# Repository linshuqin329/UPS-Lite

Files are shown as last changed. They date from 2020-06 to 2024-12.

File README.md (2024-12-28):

# UPS-Lite
UPS-Lite是一款专门为树莓派Zero所设计的UPS电源，采用一块1000mAh的聚合物锂电池进行供电，支持外部电源插入检测，支持边充边放，支持电池电量检测。

详细的使用说明请看项目文件中的使用说明文档。如有问题请联系我：416386001@qq.com

UPS-Lite is a UPS power supply specially designed for the Raspberry Pi Zero. It uses a 1000mAh polymer lithium battery for power supply, supports external power supply insertion detection, supports charging and discharging while supporting battery power detection. Support battery level detection.
 
For detailed instructions, please refer to the instructions in the project file. If you have any questions, please contact me: 416386001@qq.com

You can buy ups-lite from here   https://www.tindie.com/products/rachel/ups-lite-for-raspberry-pi-zero/

## Statement about fake UPS-Lite 
hello, first of all, thank you for your support of ups-lite. Recently, I have received feedback from many customers, they bought fake ups-lite, there are many problems, some can not read the accurate battery power value, some battery bulge phenomenon, and some serious damage to pi zero. If you buy a ups-lite like this picture, it says "Designed BY MJ" on the back, then it is a fake ups-lite, and it is recommended to stop using it for safety.

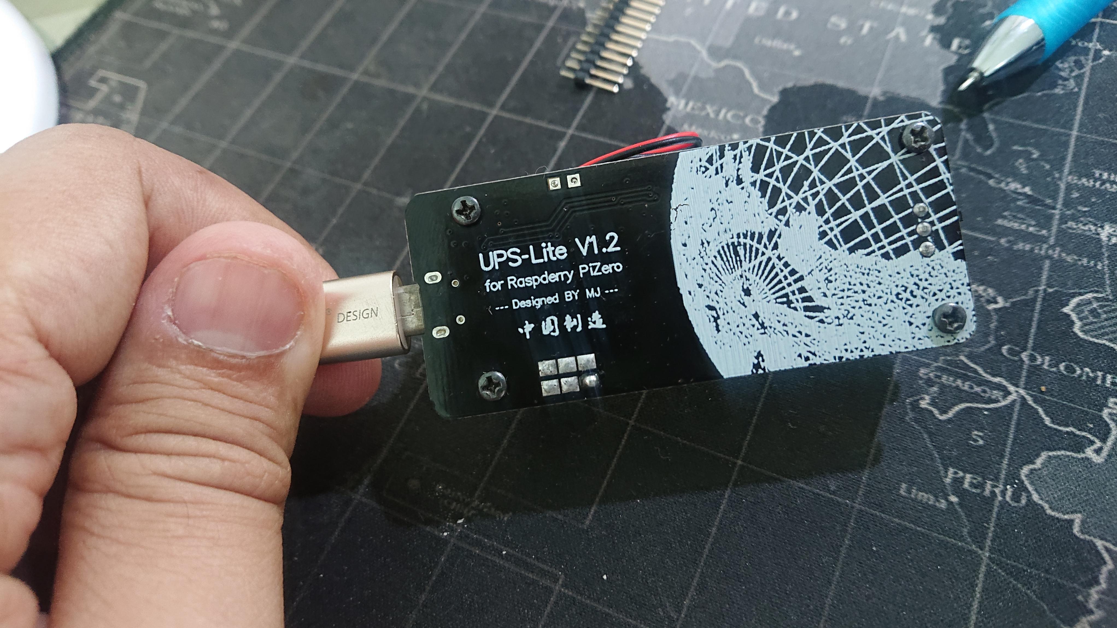
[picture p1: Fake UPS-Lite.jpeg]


# Case for UPS-Lite 
https://makerworld.com.cn/zh/models/767038#profileId-734749

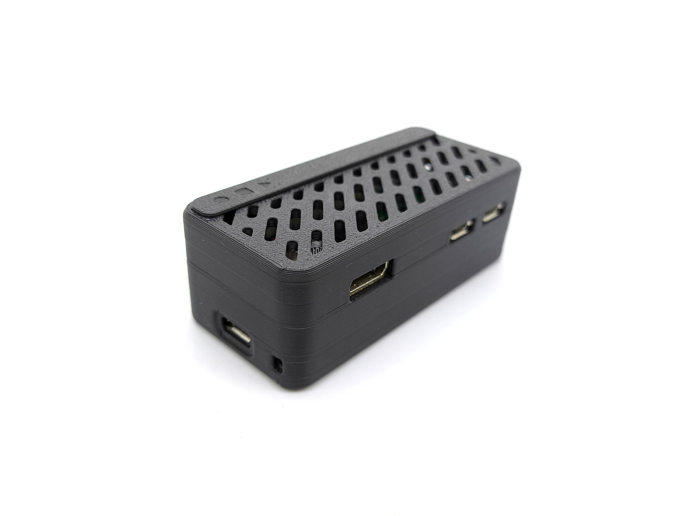
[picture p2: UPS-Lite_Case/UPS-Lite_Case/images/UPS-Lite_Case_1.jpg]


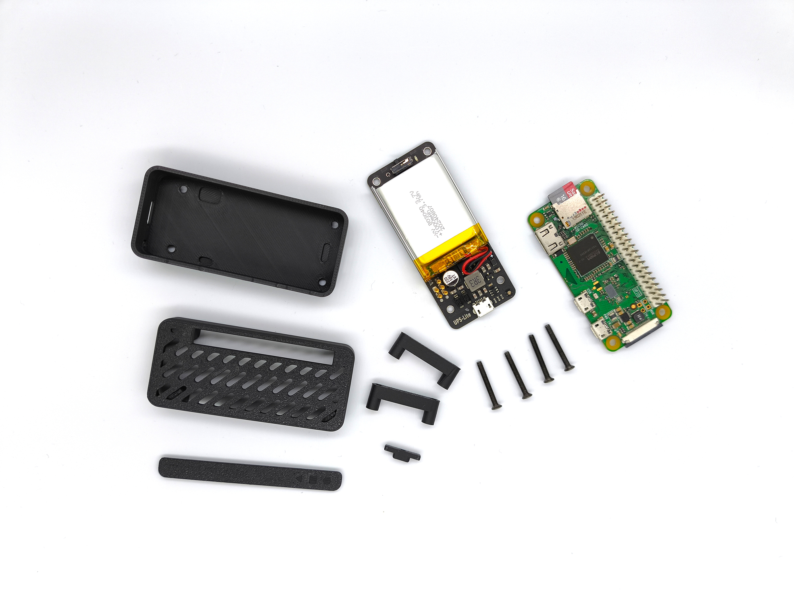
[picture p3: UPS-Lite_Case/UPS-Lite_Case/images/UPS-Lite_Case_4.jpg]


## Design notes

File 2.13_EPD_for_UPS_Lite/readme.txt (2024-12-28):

Instructions for using this board on the Pwnagotchi 

The pin definition on the e-ink screen circuit of this board is compatible with the waveshare  2.13 inch e-Paper HAT V4, 
which means that when you configure the Pwnagotchi screen, the screen type can be selected "waveshare_4"
ui.display.type = "waveshare_4"

For the use of the RTC chip DS1307Z, please refer to the detailed tutorial on Adafruit website
https://learn.adafruit.com/adding-a-real-time-clock-to-raspberry-pi

For the case, you can download the case 3D file, print and install it yourself
https://github.com/linshuqin329/UPS-Lite/tree/master/UPS-Lite_Case/UPS-Lite_EPD_Case
https://github.com/linshuqin329/UPS-Lite/tree/master/UPS-Lite_Case/UPS-Lite_EPD_Antenna_Case

//--------------------------------------------------------------------------------------------------------------------------------------

关于这个板子在Pwnagotchi 项目上的使用说明，

这个板子的墨水屏电路上的引脚定义与微雪的2.13寸墨水屏V4版本是兼容的，也就是说当你在配置Pwnagotchi 屏幕的时候，屏幕类型可以选择“waveshare_4”即可
ui.display.type = "waveshare_4"

关于RTC芯片DS1307Z的使用，请参考Adafruit网站上的相关详细教程
https://learn.adafruit.com/adding-a-real-time-clock-to-raspberry-pi

关于配套的外壳，可下载外壳3D文件，自行打印安装
https://github.com/linshuqin329/UPS-Lite/tree/master/UPS-Lite_Case/UPS-Lite_EPD_Case
https://github.com/linshuqin329/UPS-Lite/tree/master/UPS-Lite_Case/UPS-Lite_EPD_Antenna_Case

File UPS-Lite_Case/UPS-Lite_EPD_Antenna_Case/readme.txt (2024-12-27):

To install the shell, you need to prepare screws by yourself. Please refer to this file “ Screw Specification Requirement （M2.5+M2）”

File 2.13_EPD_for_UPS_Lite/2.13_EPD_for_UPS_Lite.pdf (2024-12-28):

# 2.13 inch E-Paper Display for UPS-Lite

UPS-Lite 专用 2.13 寸电子墨水屏显示板 | -- by XiaoJ

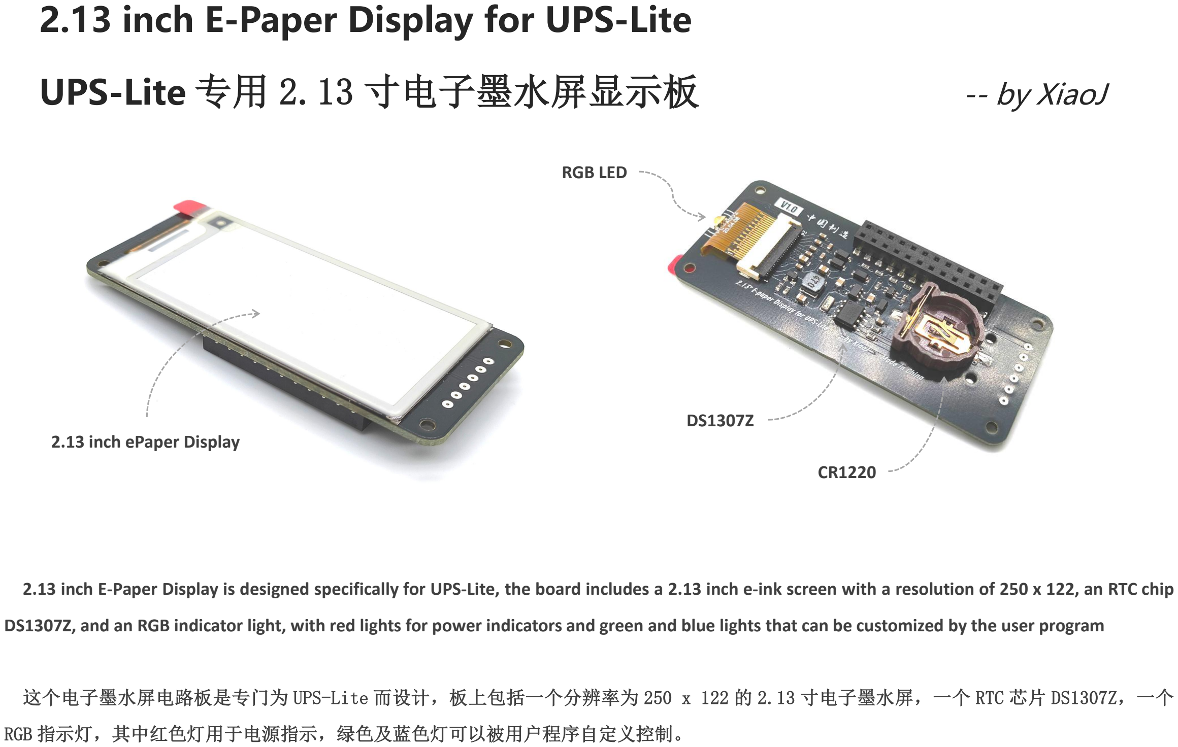
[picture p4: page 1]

### 2.13 inch ePaper Display

RGB LED

DS1307Z

CR1220

2.13 inch E-Paper Display is designed specifically for UPS-Lite, the board includes a 2.13 inch e-ink screen with a resolution of 250 x 122, an RTC chip DS1307Z, and an RGB indicator light, with red lights for power indicators and green and blue lights that can be customized by the user program

这个电子墨水屏电路板是专门为 UPS-Lite 而设计，板上包括一个分辨率为 250 x 122 的 2.13 寸电子墨水屏，一个 RTC 芯片 DS1307Z，一个

RGB 指示灯，其中红色灯用于电源指示，绿色及蓝色灯可以被用户程序自定义控制。

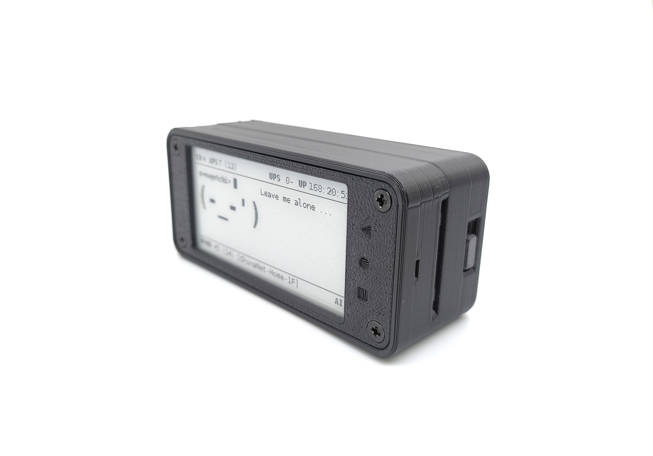
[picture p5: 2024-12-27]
UPS-Lite_Case/UPS-Lite_EPD_Case/images/UPS-Lite_EPD_Case_1.jpg

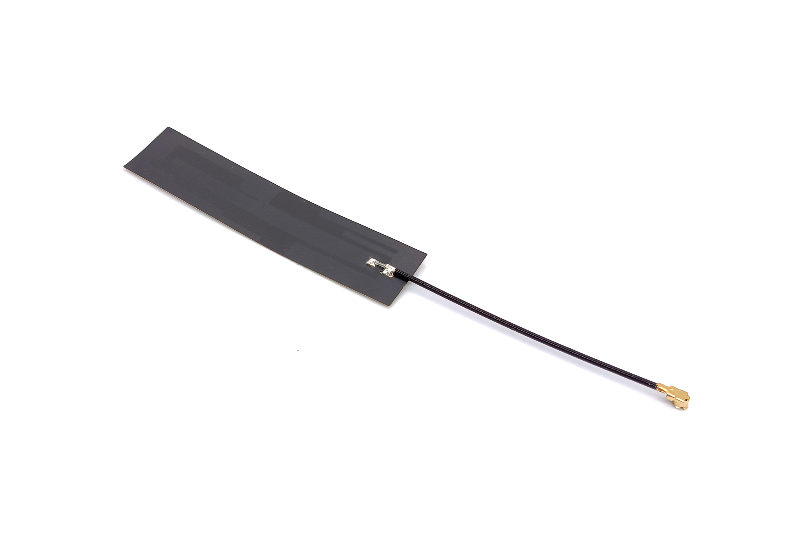
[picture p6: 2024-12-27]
UPS-Lite_Case/UPS-Lite_EPD_Antenna_Case/images/UPS-Lite_EPD_Antenna_Case_5.jpg

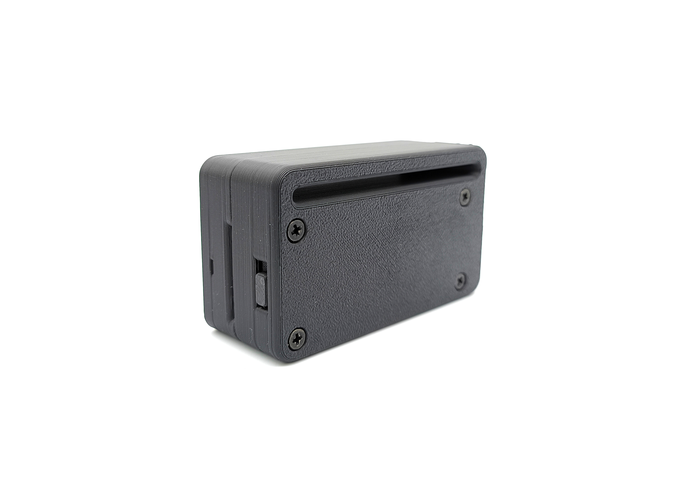
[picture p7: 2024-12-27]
UPS-Lite_Case/UPS-Lite_EPD_Antenna_Case/images/UPS-Lite_EPD_Antenna_Case_2.jpg

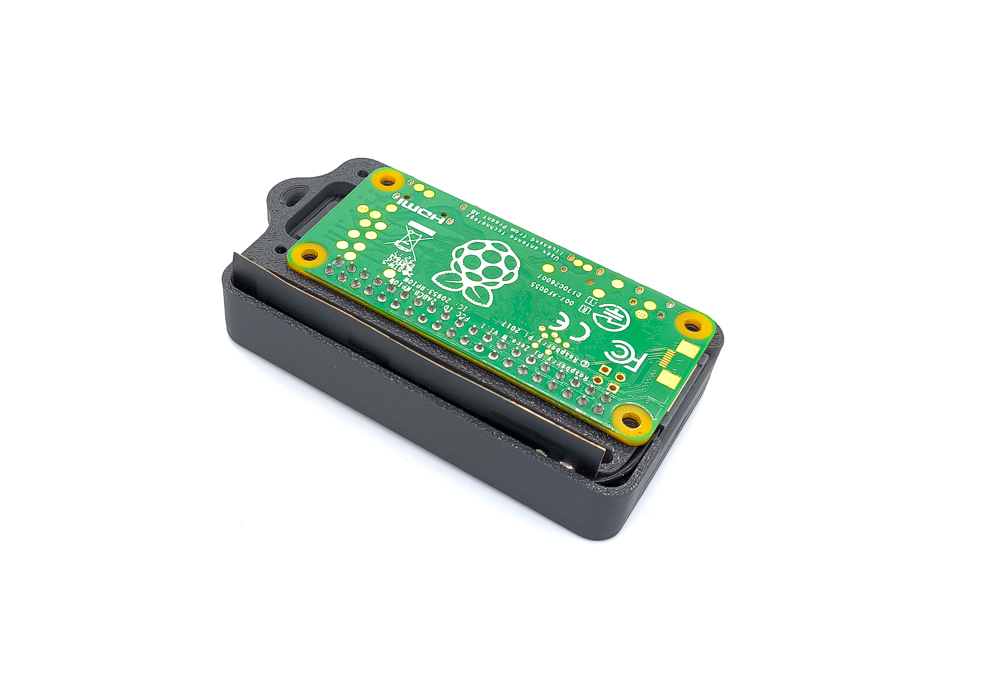
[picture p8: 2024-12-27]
UPS-Lite_Case/UPS-Lite_EPD_Antenna_Case/images/UPS-Lite_EPD_Antenna_Case_3.jpg

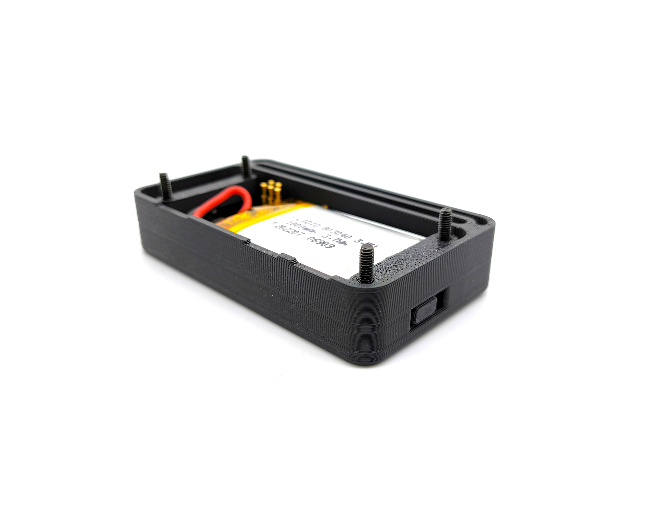
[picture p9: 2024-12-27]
UPS-Lite_Case/UPS-Lite_EPD_Antenna_Case/images/UPS-Lite_EPD_Antenna_Case_4.jpg

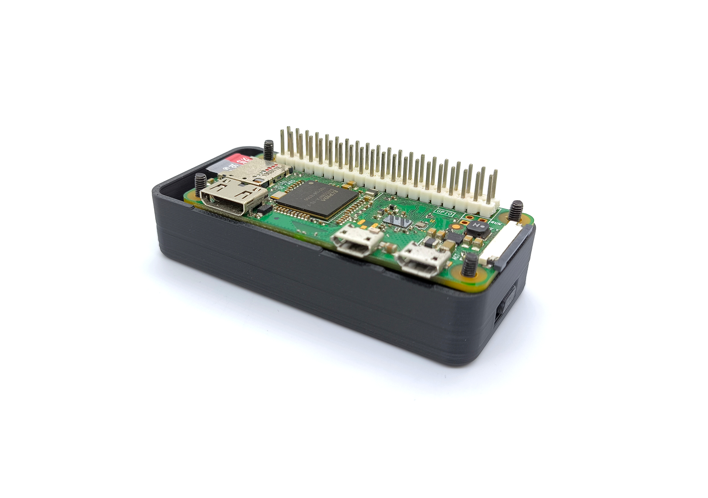
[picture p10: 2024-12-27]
UPS-Lite_Case/UPS-Lite_Case/images/UPS-Lite_Case_2.jpg

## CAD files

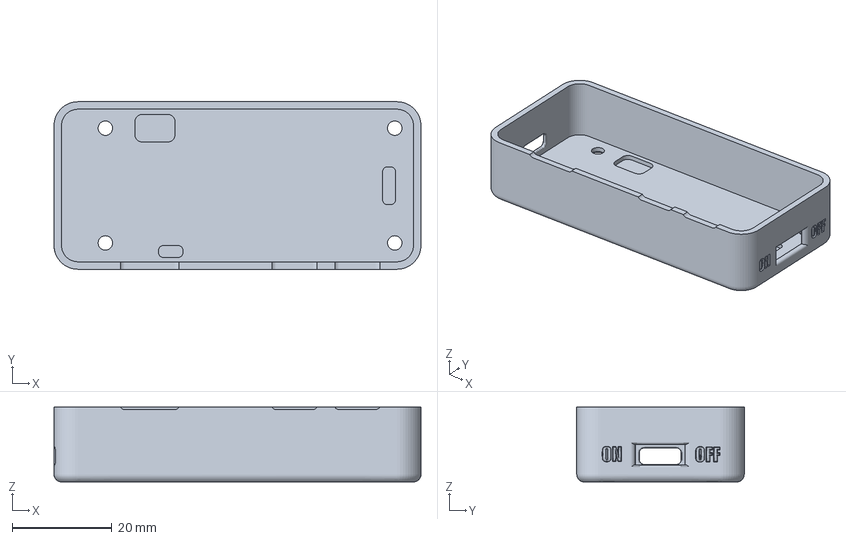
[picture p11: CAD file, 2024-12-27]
UPS-Lite_Case/UPS-Lite_Case/3mf/bottom cover.3mf
73.6 x 33.6 x 15.0 mm

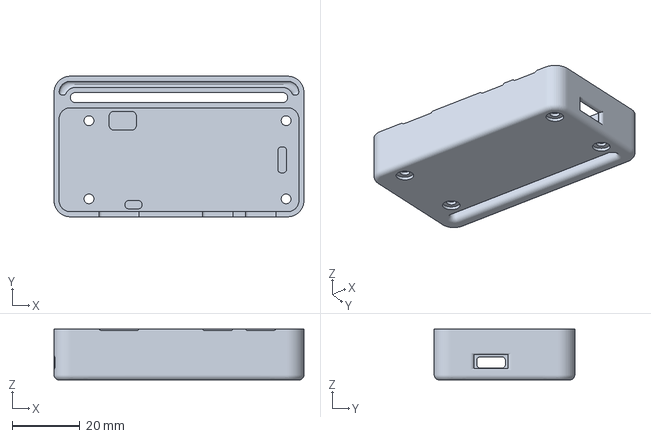
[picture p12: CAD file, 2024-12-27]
UPS-Lite_Case/UPS-Lite_EPD_Antenna_Case/3mf/bottom cover.3mf
73.6 x 41.4 x 15.0 mm

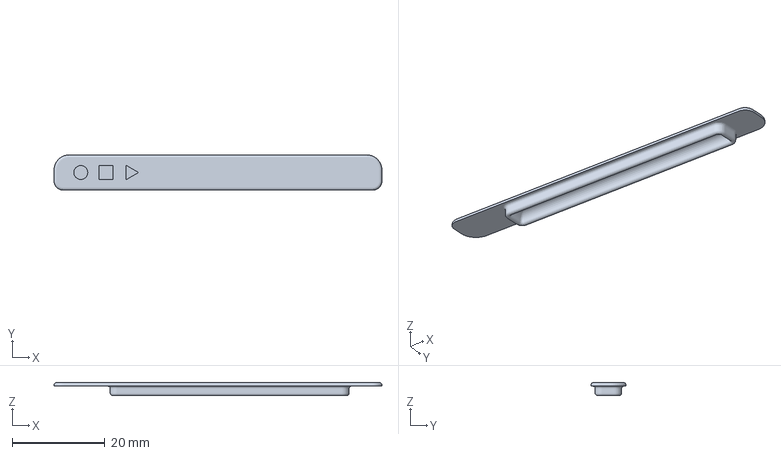
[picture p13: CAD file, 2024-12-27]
UPS-Lite_Case/UPS-Lite_Case/3mf/pin cover.3mf
70.6 x 7.61 x 2.80 mm

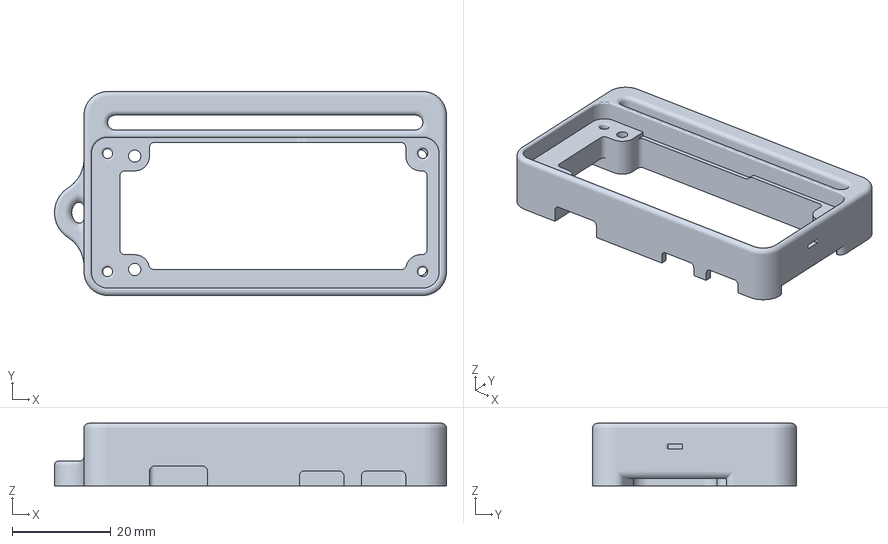
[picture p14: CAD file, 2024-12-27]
UPS-Lite_Case/UPS-Lite_EPD_Antenna_Case/3mf/screen frame.3mf
79.6 x 41.4 x 12.7 mm

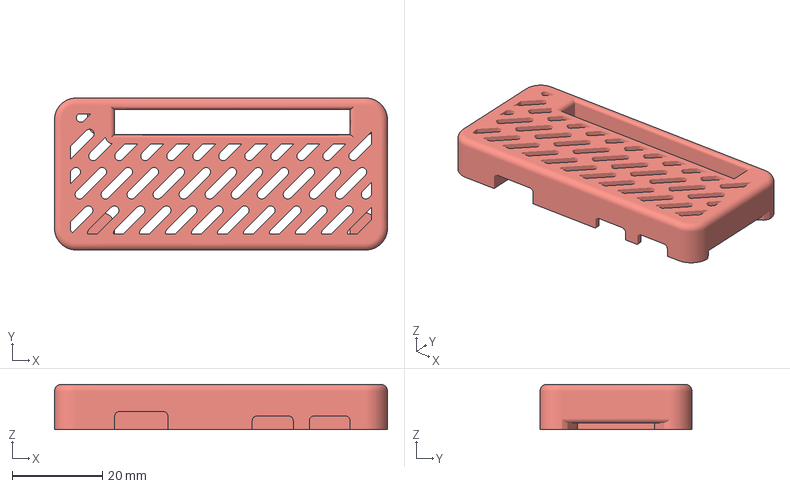
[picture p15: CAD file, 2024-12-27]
UPS-Lite_Case/UPS-Lite_Case/3mf/top cover.3mf
73.6 x 33.6 x 10.0 mm

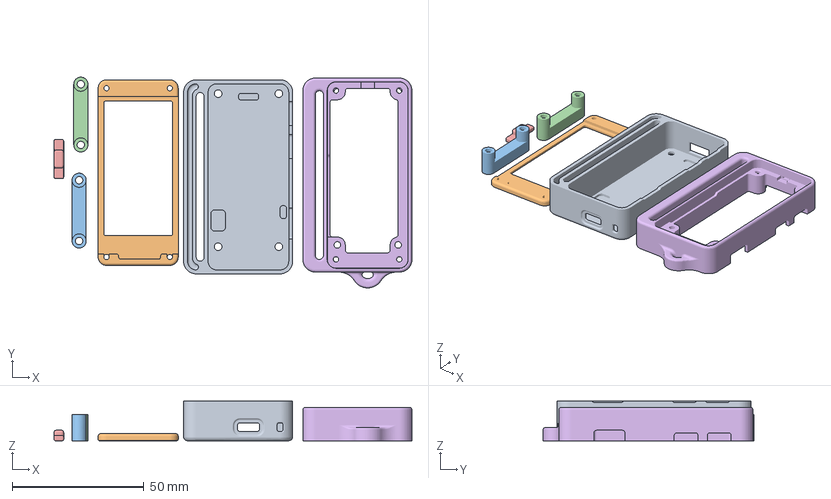
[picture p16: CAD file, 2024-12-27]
UPS-Lite_Case/UPS-Lite_EPD_Antenna_Case/3mf/print file.3mf
135.8 x 79.9 x 15.0 mm
实体1 x 4
实体2
实体3

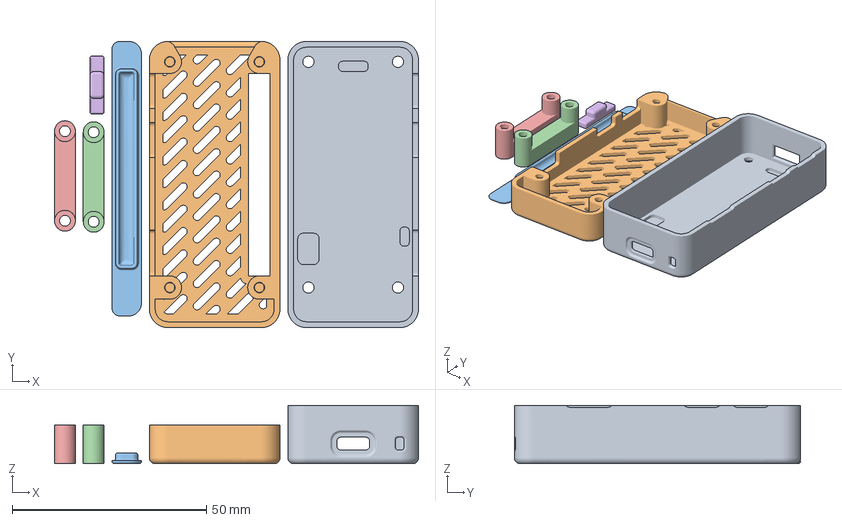
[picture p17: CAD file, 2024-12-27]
UPS-Lite_Case/UPS-Lite_Case/3mf/print file.3mf
93.6 x 73.6 x 15.0 mm
实体1 x 3
实体2
实体4
实体3

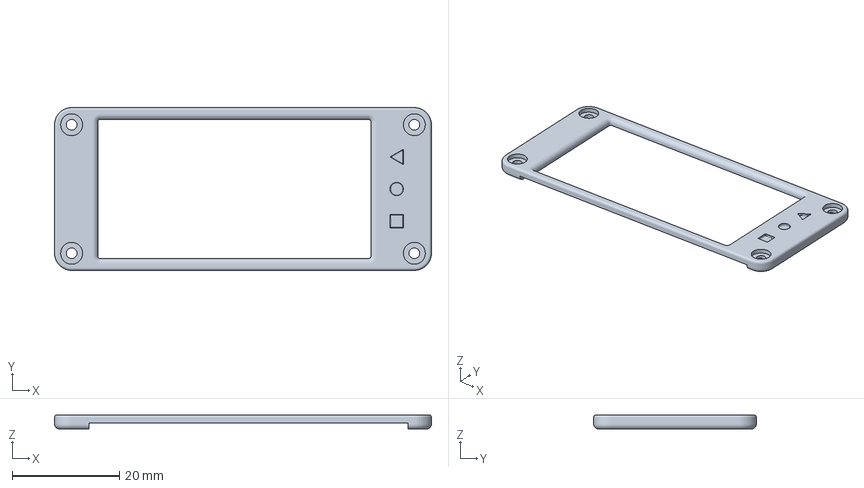
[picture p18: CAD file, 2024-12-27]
UPS-Lite_Case/UPS-Lite_EPD_Antenna_Case/3mf/screen cover.3mf
70.4 x 30.4 x 2.70 mm

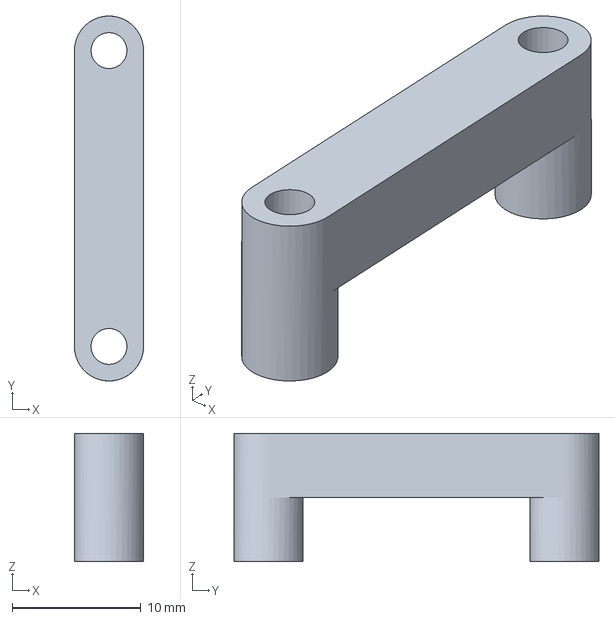
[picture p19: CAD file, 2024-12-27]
UPS-Lite_Case/UPS-Lite_EPD_Antenna_Case/3mf/pillar B.3mf
5.38 x 28.4 x 10.0 mm

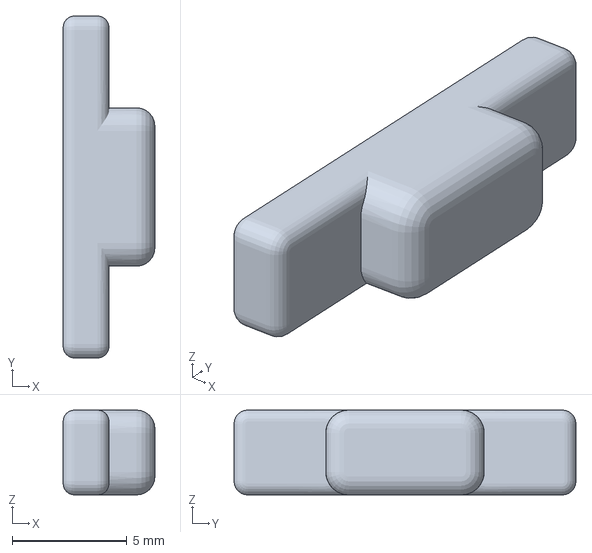
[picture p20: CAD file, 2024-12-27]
UPS-Lite_Case/UPS-Lite_EPD_Antenna_Case/3mf/switch cap.3mf
4.00 x 14.9 x 3.70 mm

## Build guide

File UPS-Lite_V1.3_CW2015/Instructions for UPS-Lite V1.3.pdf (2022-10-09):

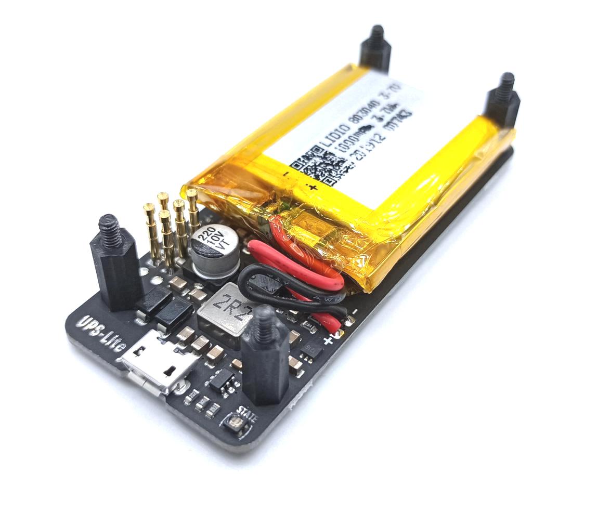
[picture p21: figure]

# 1. Introduction

UPS-Lite is a UPS power supply specially designed for Raspberry Pi Zero (hereinafter referred to as pi). It uses a 1000mAh polymer lithium battery for power supply. It supports external power supply insertion detection, supports charging and discharging while plugging in external When power is supplied, pi is powered by an external power supply. When the external power supply is unplugged, pi seamlessly switches to the lithium battery. UPS-Lite is connected to the pi through 5 Pogopin (the pi must be soldered with a 40-pin header). The power supply and battery power measurement functions of the pi are completed by the Pogopin. In addition, UPS-Lite also integrates a professional fuel gauge chip CW2015, dual-color charging status indicator.

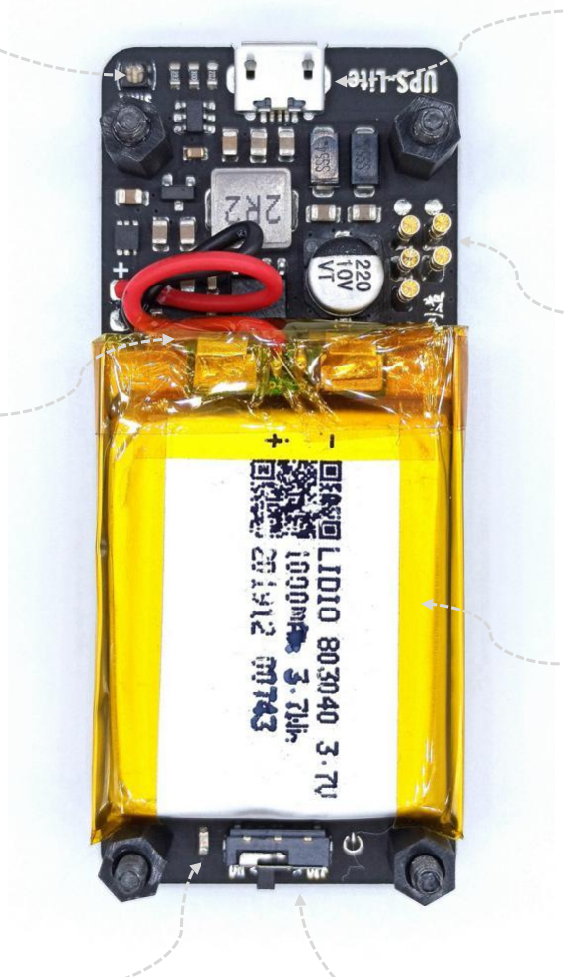
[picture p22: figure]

Power output switch

1000mAh polymer lithium battery

Pogopin

Charging interface

5V output indicator

Dual-color charging status indicator

CW2015 fuel gauge chip

Parameter :
Charging current: Max 400ma@5V
Output current: Max 1.3A@5V (only powered by battery without external power supply)
Max 2A@5V (with external power supply plugged in) Battery measurement: percentage of battery SOC, an error ±2%, the measurement errors of battery voltages ± 3mV

# 2.Install

Align the four fixing holes of pi with the four screws of the UPS, and lock the matching nuts. Note that pi needs to be soldered to use UPS-Lite. Because the connection between pi and UPS-Lite is achieved through the contact of Pogopin and pin.

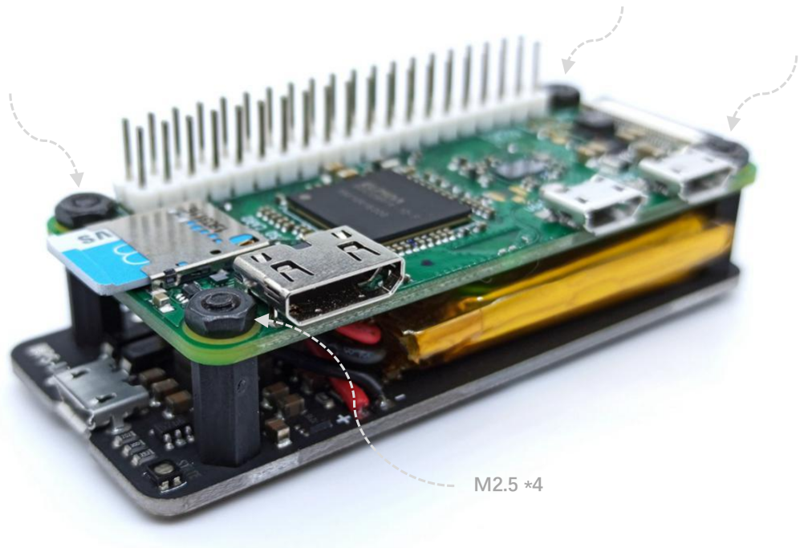
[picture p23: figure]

# 3.Function and using

### 3.1 Charging and power insertion detection function

It is recommended to use a power adapter with a power of 5V2A or above to charge the UPS-Lite. Because when the lithium battery is low, the external power adapter not only needs to supply power to the pi, but also needs to provide part of the current for the lithium battery to charge. During the charging process, the charging status indicator is red, indicating that the battery is charging. When the lithium battery is fully charged, the charging status indicator will turn green, indicating that the battery is fully charged. In addition, UPS-Lite has an external

power adapter insertion detection function. You can judge whether the external power supply is inserted by the high and low levels of the GPIO port. When the power supply is plugged in, the io4 (BCM mode) of the pi will detect a high level. When unplugging ,the pi will detect a low level, to enable the detection function, the two pads on the back of the UPS must be shorted, and the GPIO is set to the

floating input state. If the pad is not shorted, the state of the GPIO detection is unstable. See the following figure for details.

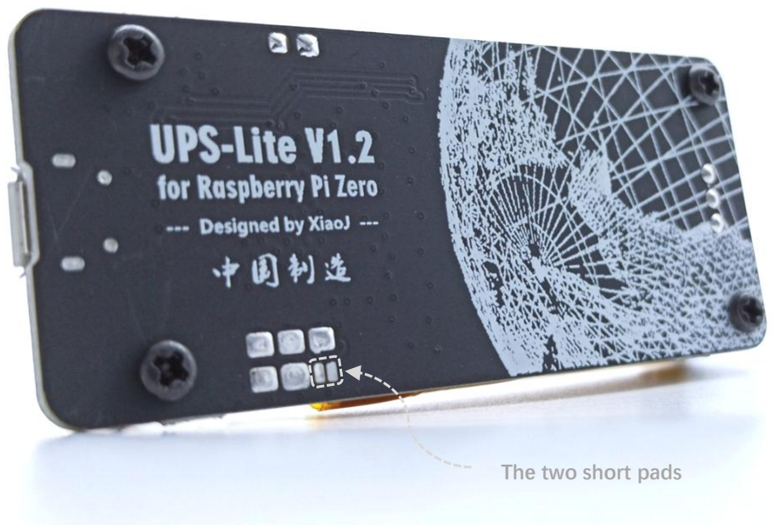
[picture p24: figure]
The two short pads

### 3.2 Battery power measurement functions

Create a script program named UPS_Lite_V1.3_CW2015.py with the nano editor. The code is as follows (see appendix for detailed code). This script uses Python's

smbus library to perform i2c read operations on the CW2015. The CW2015 device address is 0x62, the register VCELL is the 14bit battery voltage ADC measurement value, the address is 02h-03h, and the ADC measurement accuracy unit is 305uV. The register SOC is a 16-bit battery capacity percentage reading, The address is

04h-05h. The upper 8-bit unit of the SOC is 1% of the battery capacity, and the lower 8-bit unit is 1/256%. It provides the reading of the decimal point of the battery capacity percentage. Save the UPS_Lite_V1.3_CW2015.py script program to a directory you know (such as the following to the /home/pi/ directory), then run the program in Python, you can see that the program will output the current battery voltage value and the percentage of battery capacity every two seconds. In addition, due to the calculation method of the CW2015 battery capacity, when

the battery capacity reading is 1%, the battery voltage reading is about 3.5V. When the voltage of the lithium battery is 3.5V, the corresponding battery capacity is already very low, and excessive discharge will damage the battery. Therefore, when the user subsequently writes a low-power automatic shutdown program, it is recommended to automatically turn off the pi when the battery capacity is 1%. When running, when the battery voltage drops to 2.7V, the UPS-Lite protection

circuit will automatically stop supplying power. See below for specific steps

CW2015 register address and Features

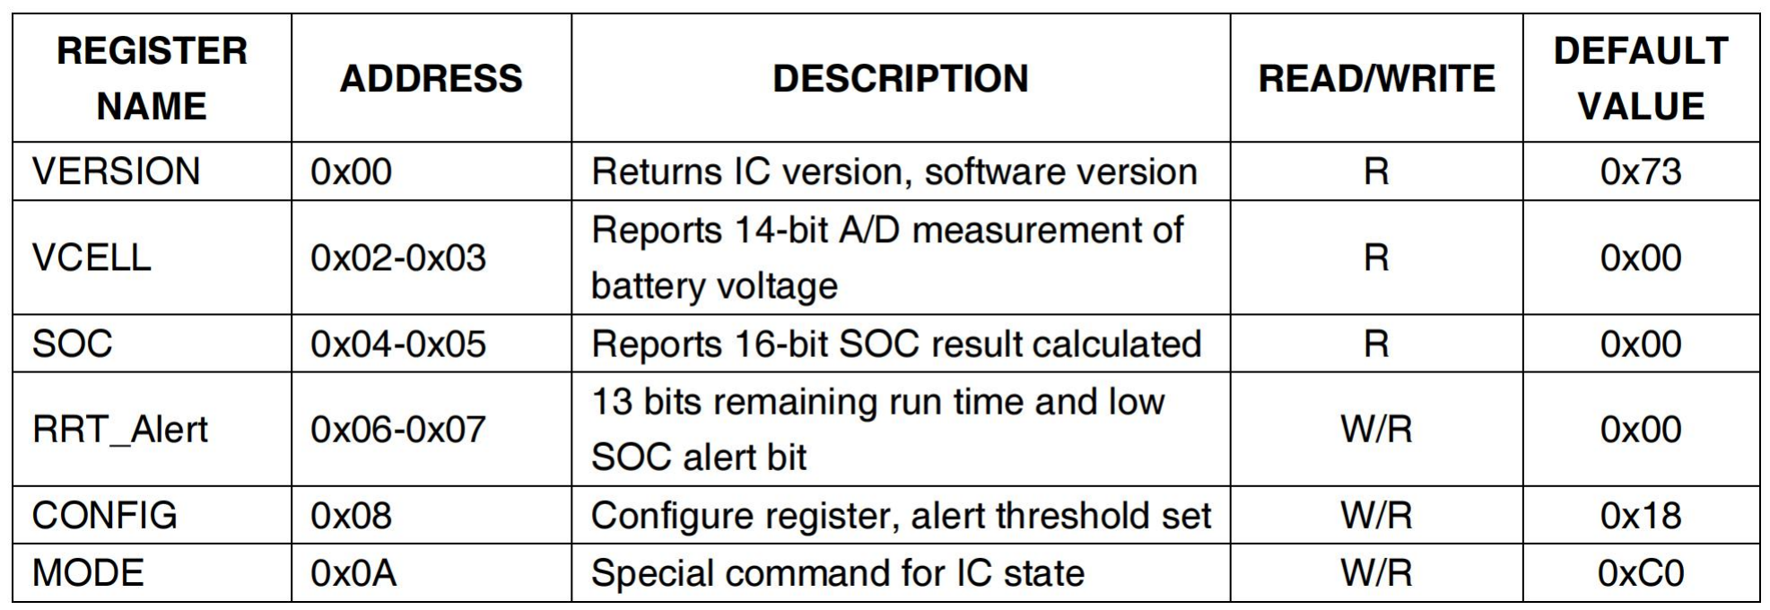
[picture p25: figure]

VCELL register

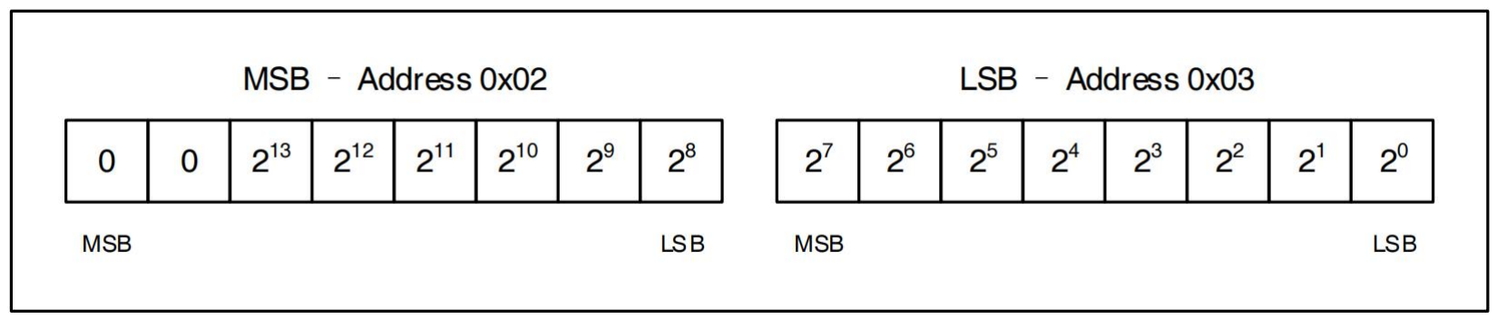
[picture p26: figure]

SOC register

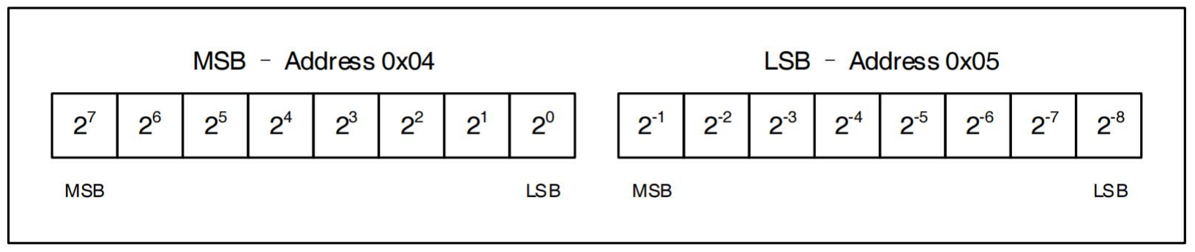
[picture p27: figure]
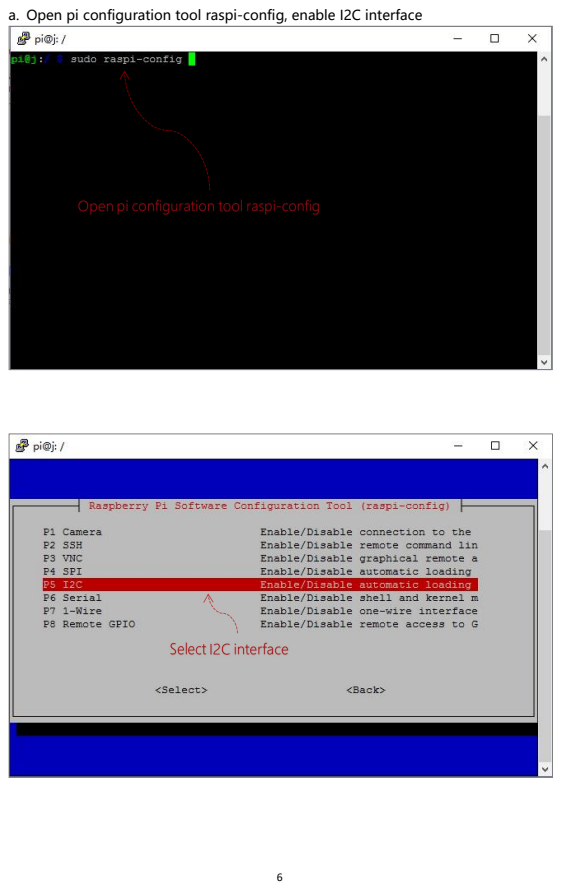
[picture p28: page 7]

a. Open pi configuration tool raspi-config, enable I2C interface

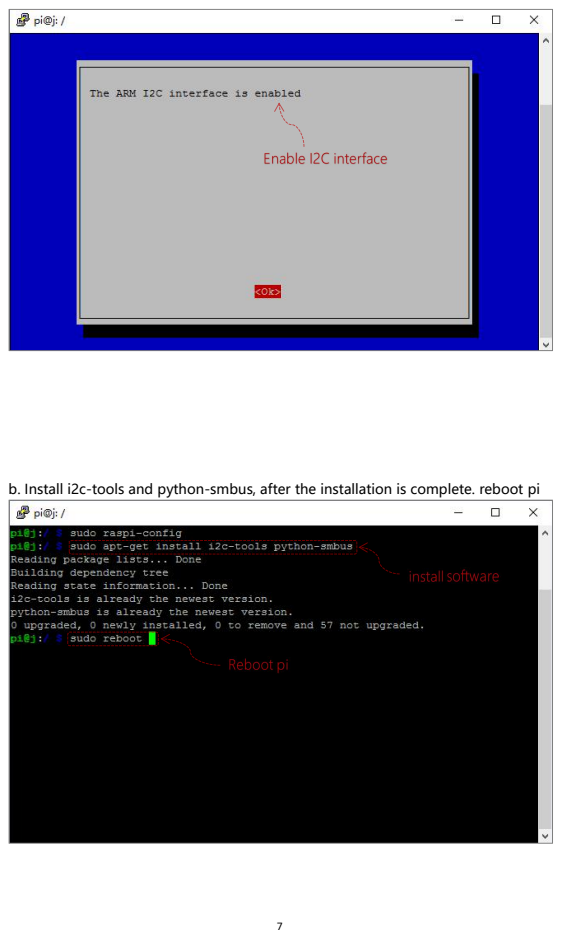
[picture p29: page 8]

b. Install i2c-tools and python-smbus, after the installation is complete. reboot pi

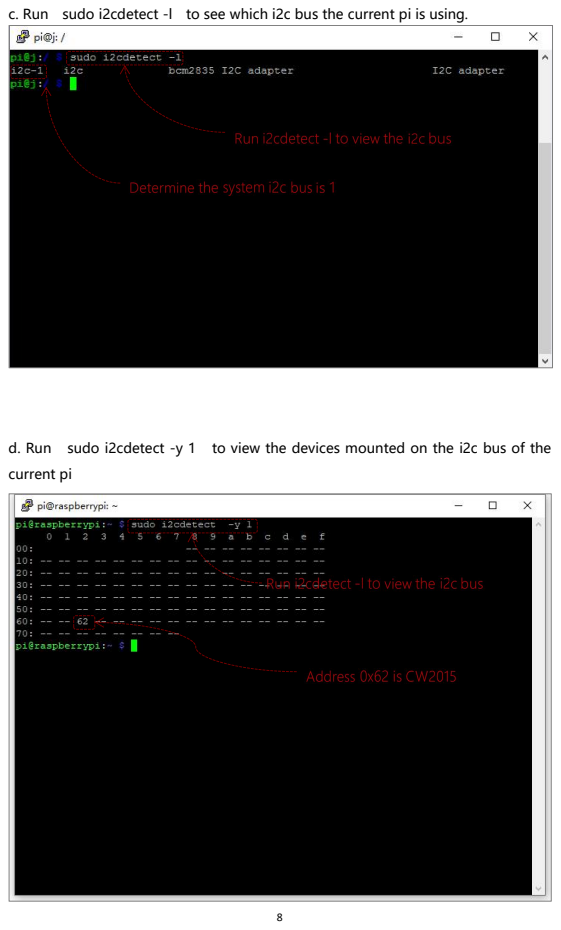
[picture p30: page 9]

c. Run sudo i2cdetect -l to see which i2c bus the current pi is using.

d. Run sudo i2cdetect -y 1 to view the devices mounted on the i2c bus of the
current pi

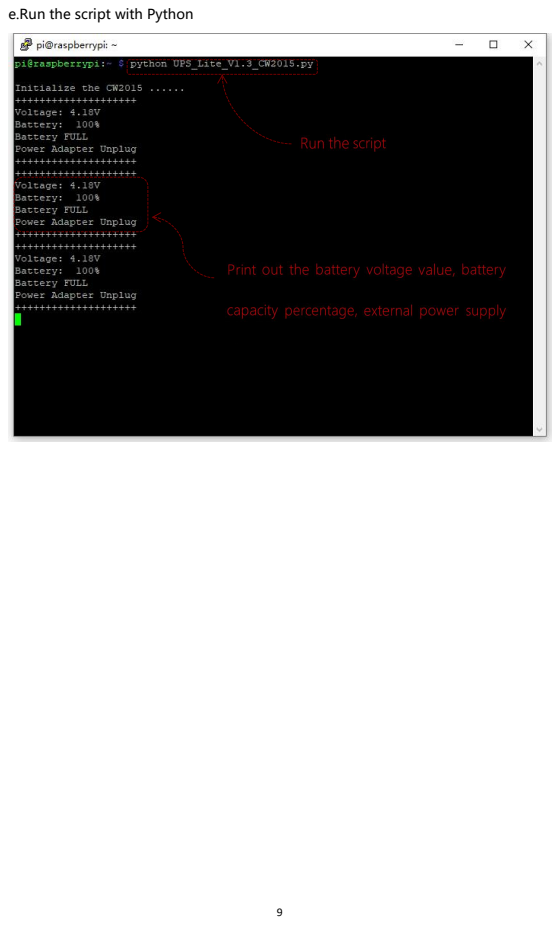
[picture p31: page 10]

e.Run the script with Python

# appendix：

Script code of UPS_Lite_V1.3_CW2015.py：

#!/usr/bin/env | python

import | struct
import | smbus
import | sys
import | time
import | RPi.GPIO | as | GPIO
CW2015_ADDRESS | | = | 0X62
CW2015_REG_VCELL | = | 0X02
CW2015_REG_SOC | | = | 0X04
CW2015_REG_MODE | | = | 0X0A
def | readVoltage(bus):
| | | | "This function returns as float the voltage from the Raspi UPS Hat
via | the | provided | SMBus | object"
| | | | read | = | bus.read_word_data(CW2015_ADDRESS, | | | | CW2015_REG_VCELL)
| | | | swapped | = | struct.unpack("<H", | | | | struct.pack(">H", | read))[0]
| | | | voltage | = | swapped | * | 0.305 | /1000
| | | | return | voltage
def | readCapacity(bus):
| | | | "This | function | returns | as | a | float | | the | remaining | capacity | of | the
battery | connected | to | the | Raspi | UPS | Hat | via | the | provided | | SMBus | object"
| | | | read | = | bus.read_word_data(CW2015_ADDRESS, | | | | CW2015_REG_SOC)
| | | | swapped | = | struct.unpack("<H", | | | | struct.pack(">H", | | | | read))[0]
| | | | capacity | = | swapped/256
| | | | return | capacity
def | QuickStart(bus): "This function wake up the CW2015 and make a quick-start fuel-gauge
calculations | "
| | bus.write_word_data(CW2015_ADDRESS, | CW2015_REG_MODE, | 0x30)

### GPIO.setmode(GPIO.BCM) GPIO.setwarnings(False)

GPIO.setup(4,GPIO.IN) | | | # GPIO4 is used to detect whether an external power
supply | is | inserted
bus = smbus.SMBus(1) | # 0 = /dev/i2c-0 (port I2C0), 1 = /dev/i2c-1 (port
I2C1)

### QuickStart(bus)

print | (" | | ")
print | ("Initialize | the | | CW2015 | ......")
while | True:
print | ("++++++++++++++++++++")
print | ("Voltage:%5.2fV" | % | readVoltage(bus))
print | ("Battery:%5i%%" | % | readCapacity(bus))
if | readCapacity(bus) | == | 100:
| | print | ("Battery | FULL")
if | readCapacity(bus) | < | 5:
| | print | ("Battery | LOW")
#GPIO | | is | | high | when | power | is | | plugged | | in

| if | | (GPIO.input(4) | | | | | == | | GPIO.HIGH):
| | | | | | print | ("Power | | | Adapter | | Plug | In | ")
| if | | (GPIO.input(4) | | | | | == | | GPIO.LOW):
| | | | | | print | ("Power | | | Adapter | | Unplug")
print | ("++++++++++++++++++++")

### time.sleep(2)

Schematic Reference Part：

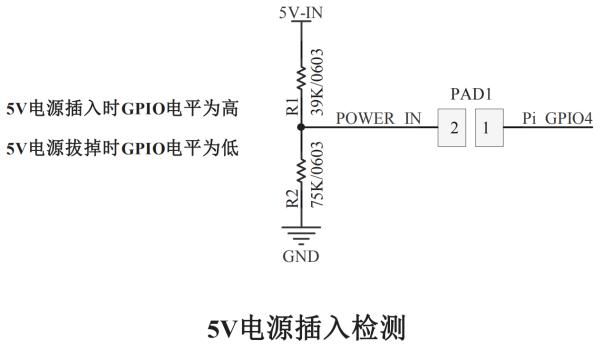
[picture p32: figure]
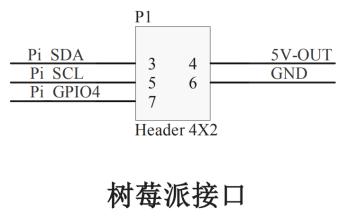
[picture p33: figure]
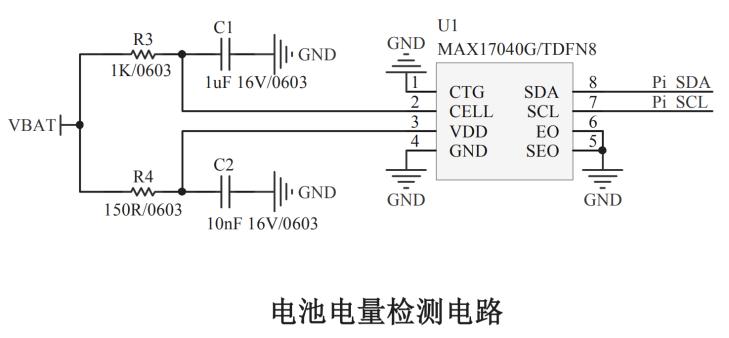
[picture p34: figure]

If you have other questions, please contact me: 416386001@qq.com

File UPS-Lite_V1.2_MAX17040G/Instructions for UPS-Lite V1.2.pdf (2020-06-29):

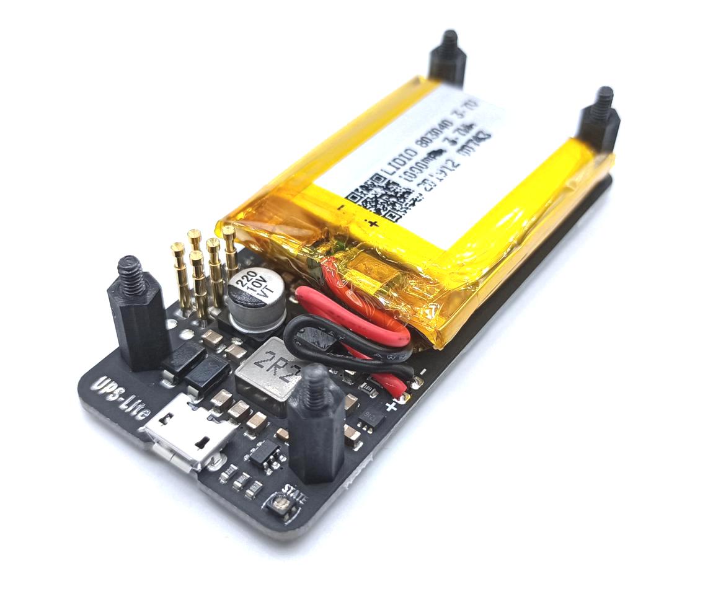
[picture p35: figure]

# 1. Introduction

UPS-Lite is a UPS power supply specially designed for Raspberry Pi Zero (hereinafter referred to as pi). It uses a 1000mAh polymer lithium battery for power supply. It supports external power supply insertion detection, supports charging and discharging while plugging in external When power is supplied, pi is powered by an external power supply. When the external power supply is unplugged, pi seamlessly switches to the lithium battery. UPS-Lite is connected to the pi through 5 Pogopin (the pi must be soldered with a 40-pin header). The power supply and battery power measurement functions of the pi are completed by the Pogopin. In addition, UPS-Lite also integrates a professional fuel gauge chip MAX17040G, dual-color charging status indicator.

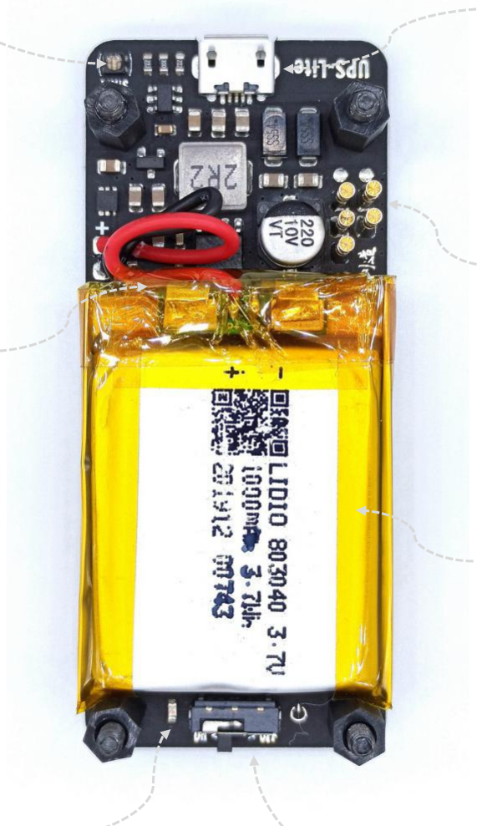
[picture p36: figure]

Power output switch

1000mAh polymer lithium battery

Pogopin

Charging interface

5V output indicator

Dual-color charging status indicator

MAX17040G fuel gauge chip

Parameter :
Charging current: Max 400ma@5V
Output current: Max 1.3A@5V (only powered by battery without external power supply) Max 2A@5V (with external power supply plugged in) Battery measurement: percentage of battery SOC, an error ±2%, the measurement errors of battery voltages ± 3mV

# 2.Install

Align the four fixing holes of pi with the four screws of the UPS, and lock the matching nuts. Note that pi needs to be soldered to use UPS-Lite. Because the connection between pi and UPS-Lite is achieved through the contact of Pogopin and pin.

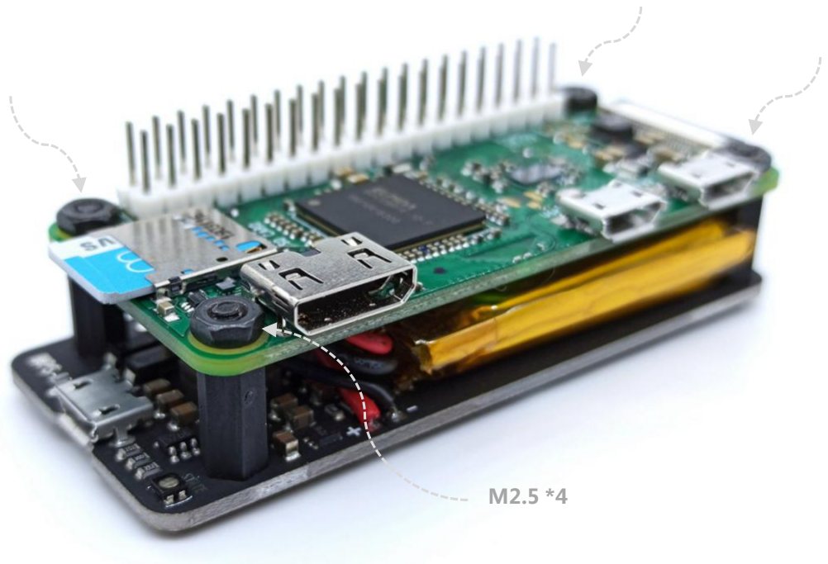
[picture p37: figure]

# 3.Function and using

### 3.1 Charging and power insertion detection function

It is recommended to use a power adapter with a power of 5V2A or above to charge the UPS-Lite. Because when the lithium battery is low, the external power adapter not only needs to supply power to the pi, but also needs to provide part of the current for the lithium battery to charge. During the charging process, the charging status indicator is red, indicating that the battery is charging. When the lithium battery is fully charged, the charging status indicator will turn green, indicating that the battery is fully charged. In addition, UPS-Lite has an external

power adapter insertion detection function. You can judge whether the external power supply is inserted by the high and low levels of the GPIO port. When the power supply is plugged in, the io4 (BCM mode) of the pi will detect a high level. When unplugging ,the pi will detect a low level, to enable the detection function, the two pads on the back of the UPS must be shorted, and the GPIO is set to the

floating input state. If the pad is not shorted, the state of the GPIO detection is unstable. See the following figure for details.

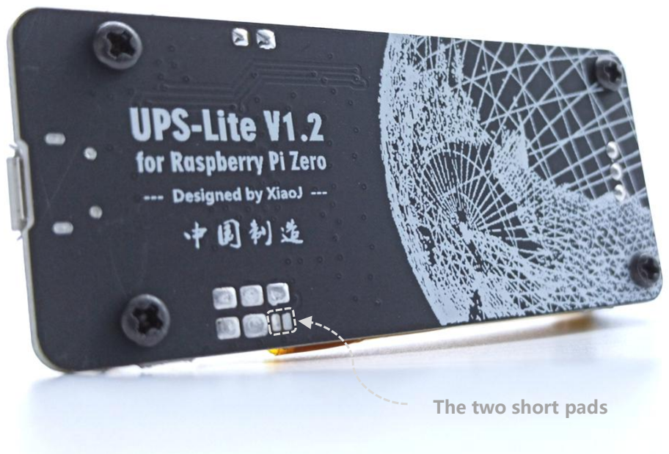
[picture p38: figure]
The two short pads

### 3.2 Battery power measurement functions

Create a script program named UPS_Lite.py with the nano editor. The code is as follows (see appendix for detailed code). This script uses Python's smbus library to perform i2c read operations on the MAX17040G. The MAX17040G device address is 0x36, the register VCELL is the 12bit battery voltage ADC measurement value, the address is 02h-03h, and the ADC measurement accuracy unit is 1.25mV. The register SOC is a 16-bit battery capacity percentage reading, The address is 04h-05h. The upper 8-bit unit of the SOC is 1% of the battery capacity, and the lower 8-bit unit is 1/256%. It provides the reading of the decimal point of the battery capacity percentage. Save the UPS_Lite.py script program to a directory you know (such as the following to the /home/pi/ directory), then run the program in Python, you can see that the program will output the current battery voltage value and the percentage of battery capacity every two seconds. In addition, due to the calculation method of the MAX17040G battery capacity, when the battery capacity reading is 1%, the battery voltage reading is about 3.5V. When the voltage of the lithium battery is 3.5V, the corresponding battery capacity is already very low, and excessive discharge will damage the battery. Therefore, when the user subsequently writes a low-power automatic shutdown program, it is recommended to automatically turn off the pi when the battery capacity is 1%. When running, when the battery voltage drops to 2.7V, the UPS-Lite protection circuit will automatically stop supplying power. See below for specific steps

MAX17040G register address and Features

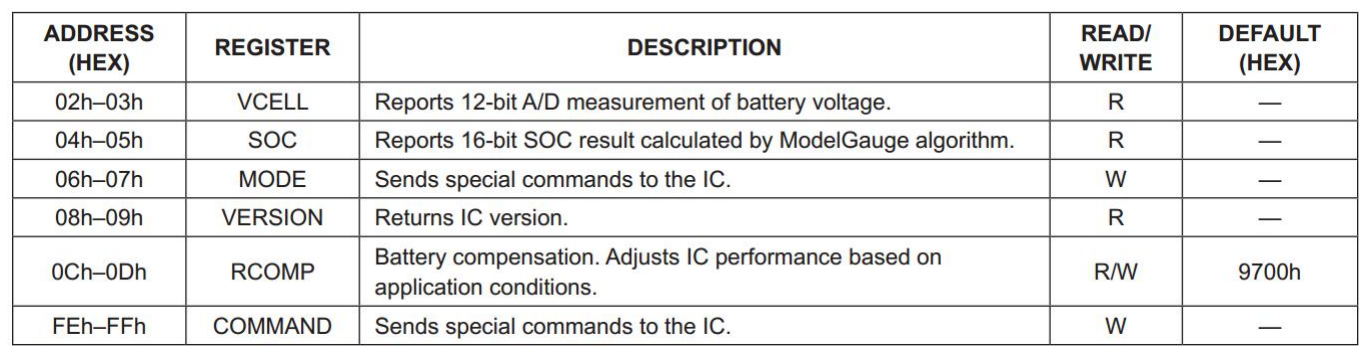
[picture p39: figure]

VCELL register

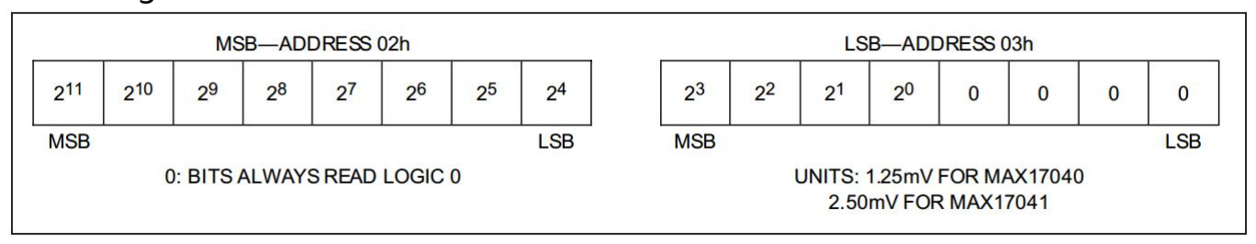
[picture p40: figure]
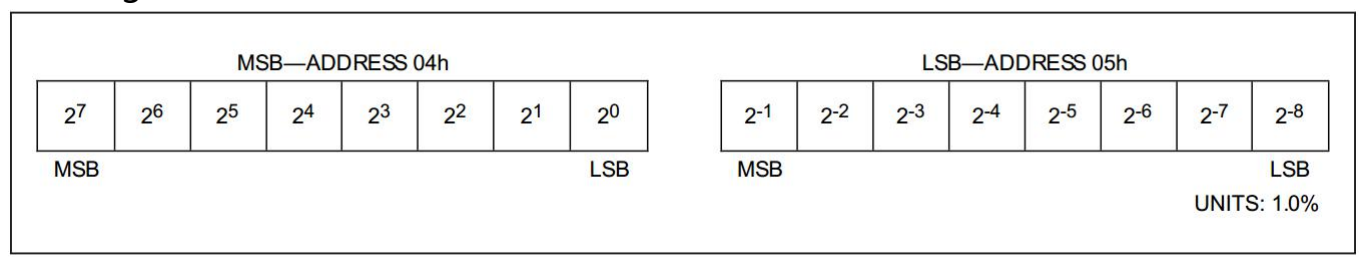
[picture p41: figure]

SOC register

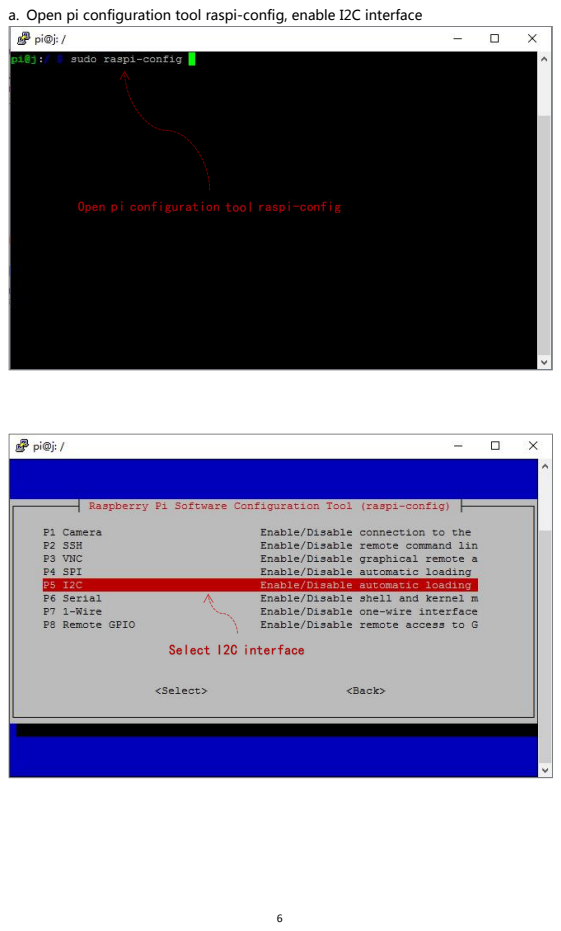
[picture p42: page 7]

a. Open pi configuration tool raspi-config, enable I2C interface

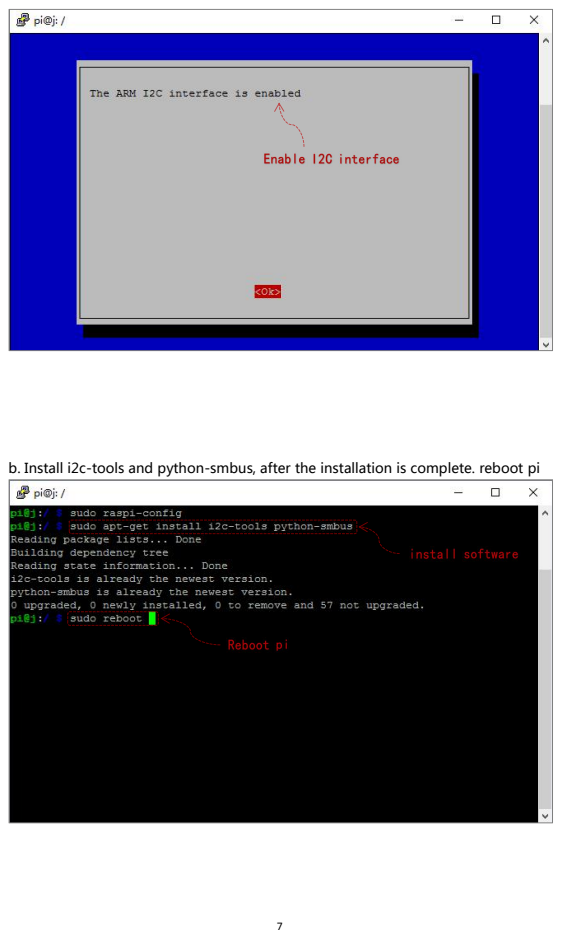
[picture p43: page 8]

b. Install i2c-tools and python-smbus, after the installation is complete. reboot pi

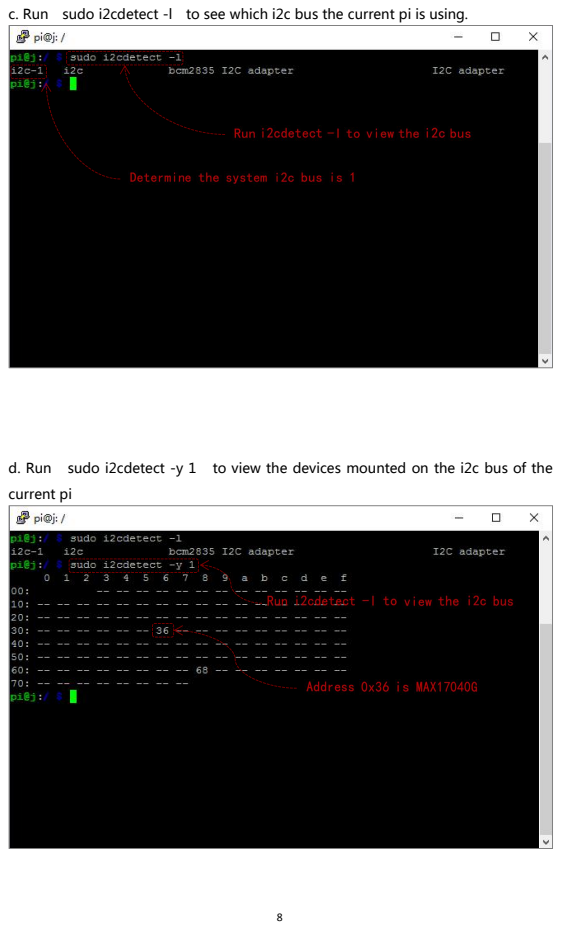
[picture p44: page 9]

c. Run sudo i2cdetect -l to see which i2c bus the current pi is using.

d. Run sudo i2cdetect -y 1 to view the devices mounted on the i2c bus of the
current pi

e. Use nano editor to create the following UPS_Lite.py script program (see appendix for detailed code)

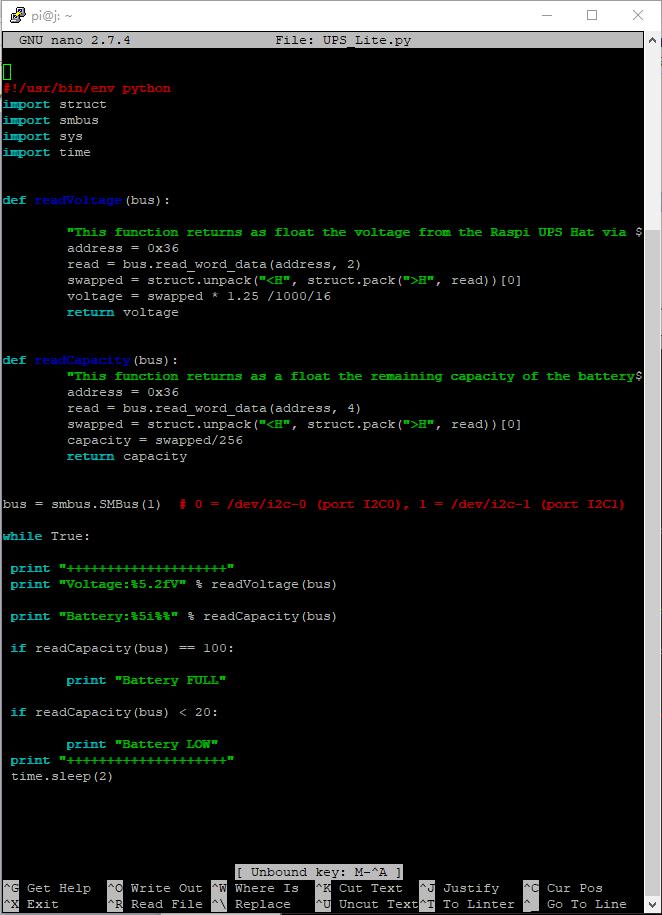
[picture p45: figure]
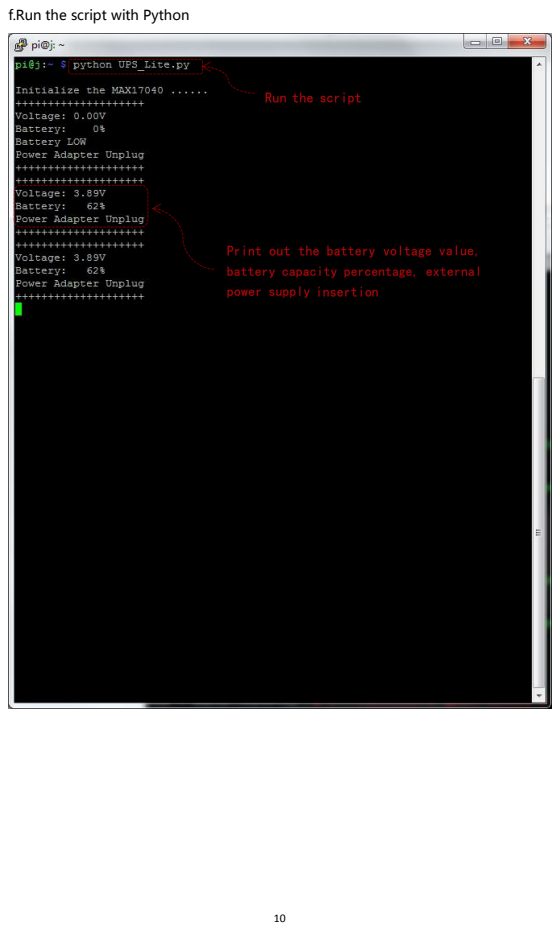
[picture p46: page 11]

f.Run the script with Python

# appendix：

Script code of UPS_Lite.py：

#!/usr/bin/env python

import struct
import smbus
import sys
import time
import RPi.GPIO as GPIO

def readVoltage(bus):

"This function returns as float the voltage from the Raspi UPS Hat via the provided SMBus object"
address = 0x36
read = bus.read_word_data(address, 0X02)
swapped = struct.unpack("<H", struct.pack(">H", read))[0] voltage = swapped * 1.25 /1000/16
return voltage

def readCapacity(bus):
"This function returns as a float the remaining capacity of the battery connected to the Raspi UPS Hat via the provided SMBus object"
address = 0x36
read = bus.read_word_data(address, 0X04)
swapped = struct.unpack("<H", struct.pack(">H", read))[0] capacity = swapped/256
return capacity

def QuickStart(bus):
address = 0x36
bus.write_word_data(address, 0x06,0x4000)

def PowerOnReset(bus):
address = 0x36
bus.write_word_data(address, 0xfe,0x0054)

GPIO.setmode(GPIO.BCM)
GPIO.setwarnings(False)
GPIO.setup(4,GPIO.IN)

bus = smbus.SMBus(1) # 0 = /dev/i2c-0 (port I2C0), 1 = /dev/i2c-1 (port I2C1)

PowerOnReset(bus)
QuickStart(bus)

print " "
print "Initialize the MAX17040 ......"

while True:

print "++++++++++++++++++++"
print "Voltage:%5.2fV" % readVoltage(bus) print "Battery:%5i%%" % readCapacity(bus)

if readCapacity(bus) == 100:
print "Battery FULL"

if readCapacity(bus) < 5:
print "Battery LOW"

if (GPIO.input(4) == GPIO.HIGH): print "Power Adapter Plug In "

if (GPIO.input(4) == GPIO.LOW): print "Power Adapter Unplug"

print "++++++++++++++++++++" time.sleep(2)

Schematic Reference Part：

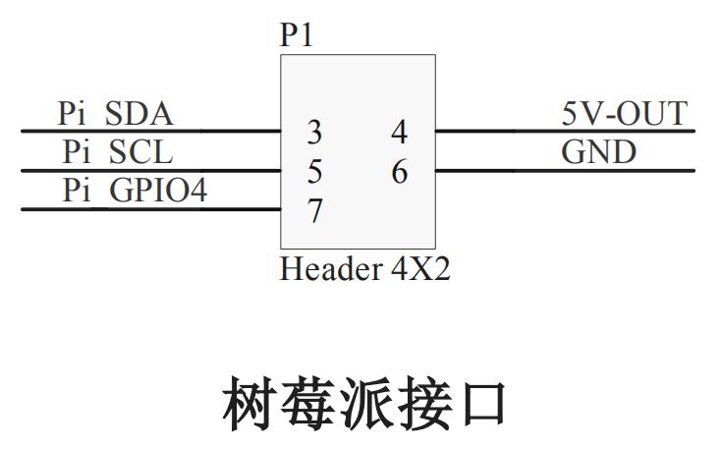
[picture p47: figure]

References：

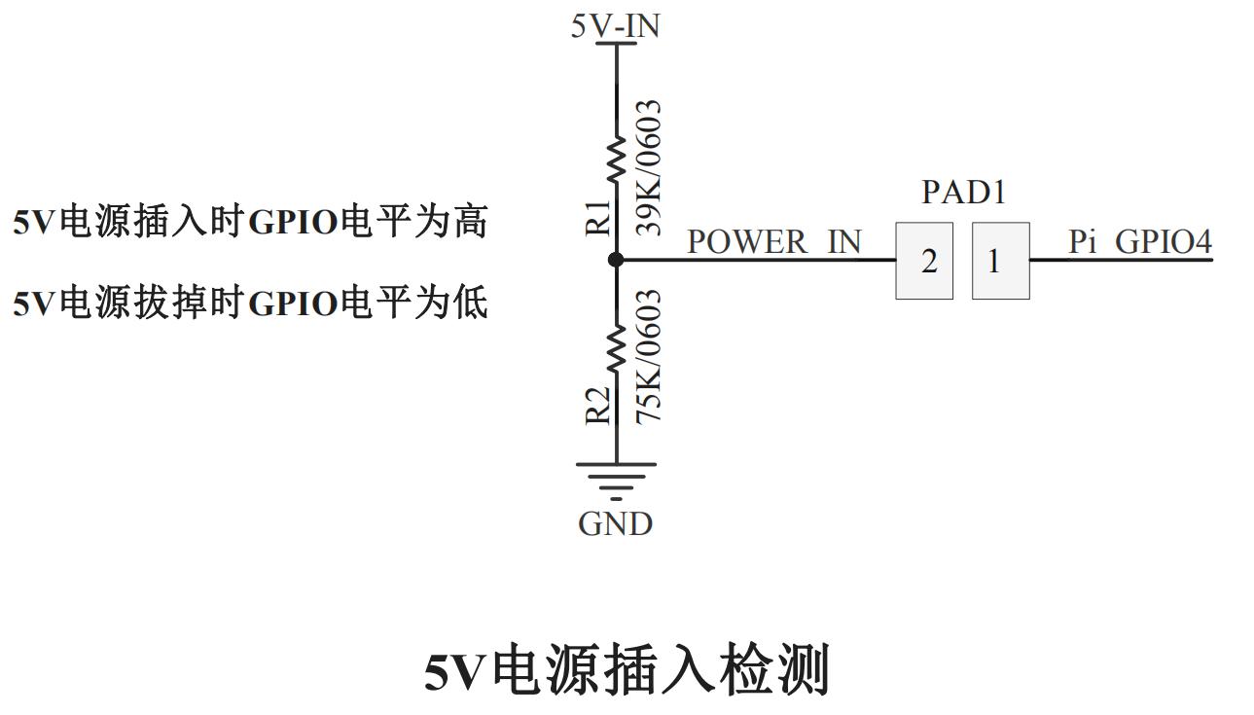
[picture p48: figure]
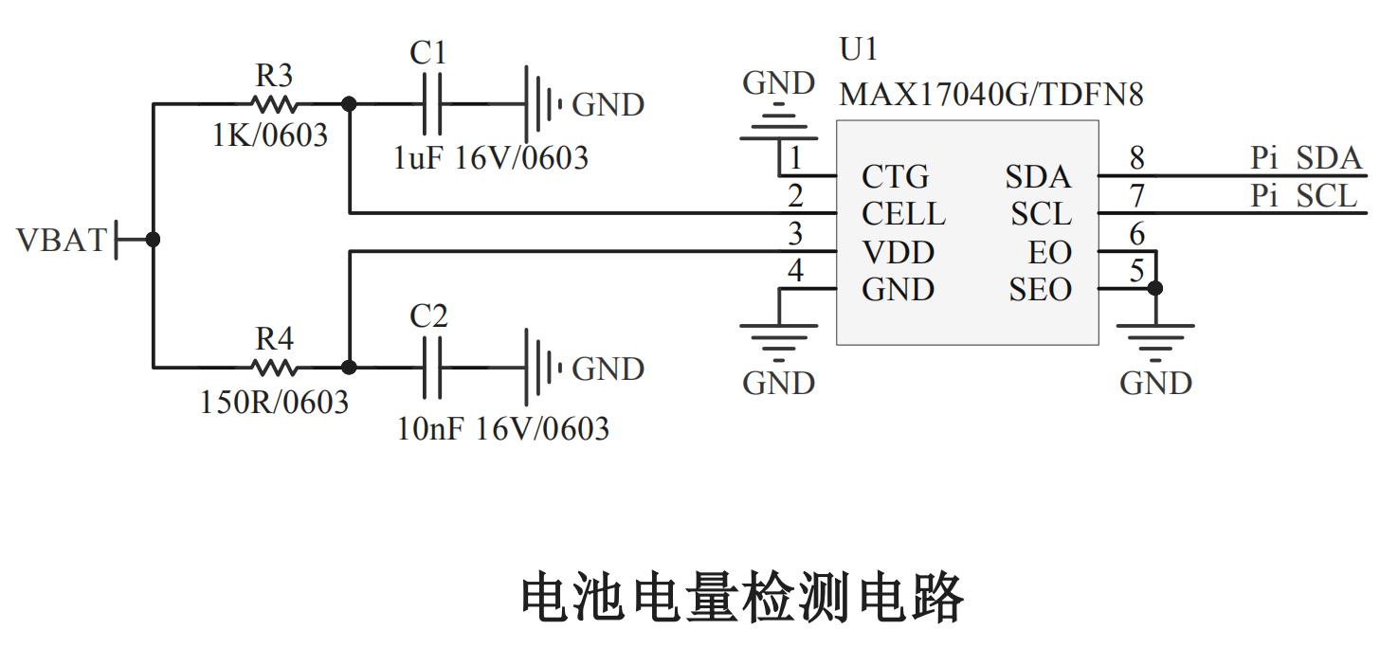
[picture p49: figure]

MAX17040 Compact, low-cost 1S/2S fuel gauge - Maxim https://www.maximintegrated.com/cn/products/power/battery-management/MAX17040.html

If you have other questions, please contact me: 416386001@qq.com

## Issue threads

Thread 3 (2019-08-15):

Is there a way to trigger a boot when external power is applied?

traindriverrev, 2019-08-15:
Is there a way to trigger a boot when external power is applied?

THX723, 2020-09-20:
@traindriverrev Were you able to get anywhere with this?

akula3, 2020-09-25:
I'M also interesed in this function

THX723, 2020-09-26:
Under normal operation, the answer is unfortunately NO.

However, there is a corner case in which it would work. That is if the battery is allowed to run down completely (<1% SOC), where the on-board circuit cut-off occurs. Only then will the Pi power up again, when external power is re-applied to the UPS-Lite input. That was meant as a safety mechanism to protect the lithium battery. I also wouldn't recommend relying on that method, as running lithium batteries down to 1% is extreme hard on its life. For extended service life, keep lithium operating SOC 80%-20% (70%-30% even better).

Rumor has it a newer hardware version is being worked on and would have the behavior we're looking for.

akula3, 2020-09-27:
THX723, can you please post a link to you mentioned hardware?

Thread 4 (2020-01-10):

Bigger battery

N2Network, 2020-01-10:
I swapped out the battery for a 10,000mAh battery. Curious if it's possible to change the capacity in the code so it reports correctly?

Fidelity88, 2020-02-08:
I think you can make adjustments in the python script. Otherwise in the manual is something about a serial connection to probably re-program the board. See #1 for the partially translated English manual.

Also, do you have a link to the battery you used?

LMoesman1998, 2020-09-14:
> I swapped out the battery for a 10,000mAh battery. Curious if it's possible to change the capacity in the code so it reports correctly?

Could you tell me what battery you used? Want to upgrade the battery as well, but not sure what to look for.

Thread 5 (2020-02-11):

Detecting external power

briggySmalls, 2020-02-11:
The schematic seems to indicate `Vin` is connected to `GPIO7`.

Inspecting the pogo pins it looks like something is connected to `GPIO4` or header pin number 7. So I assume this is what is meant?

However when I read this pin as an input I don't seem to get anything corresponding to Vin.

Can I detect the presence of external power with the UPSLite?

briggySmalls, 2020-02-11:
For anyone else looking into this issue:

I read the English-language translation of the manual #1 and found:

> Also UPS-Lite insertion detecting function with a power adapter, the insertion of the power pi io4 (BCM number) detects the high level, when pulled low, enabling the weld shorting function requires two back of the UPS disc, as shown below in detail.

And translating the correcsponding text in the new manual (v1.2):

> In addition, UPS-Lite has a power adapter insertion detection function, which can increase the high and low levels of the GPIO port to determine whether an external power supply is plugged in. The io4 (BCM number) of pi will detect a high level when plugged in, and low when unplugged. Level. To enable this function, you need to short the two pads on the back of the UPS. See the figure below for details.

With the diagram:

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

This made me realise I had not read the schematic correctly, there are clearly two pads labelled:

![Screenshot 2020-02-11 at 11 35 44](https://user-images.githubusercontent.com/11054133
/74233712-1a316580-4cc3-11ea-9c19-295af946137b.png)

Whilst I have not yet tested this, it looks like this will solve my issue.

briggySmalls, 2020-02-12:
It works!

lgbrownjr, 2020-06-03:
> It works!

Can you please explain how you accomplished this?  I see the two pads, but due to lack of experience, i want to be sure before potentially destroying my UPS.  Did you simply solder the two pads together?
Also, as i understand, gpio4 is also responsible for providing the battery capacity, so how does shorting the two pads affect the values?

Thanks!

briggySmalls, 2020-06-03:
## TLDR;

Yes, just solder the two pads together.

## Explanation

The effect of that is to make an electrical connection between `PAD1` and `PAD1_2` in the schematic that I posted above. Otherwise `PAD1` is just floating (not connected to anything at all).

As for your other question, it is worth being explicit about which [pin number system](https://pinout.xyz/pinout/i2c#) we are using. The battery capacity is obtained by communicating with the fuel gague on the UPSLite via the I2C protocol (a pair of pins). Specifically it uses I2C1 which is located on pins with BCM numbers 2 & 3. Thats the 3rd and 5th pins if you are looking at the physical header.

So no, BCM4 (AKA physical pin 7) is not used in communicating with the fuel gague. It needs to be configured as a simple GPIO, an input.

Closed 2020-02-12.

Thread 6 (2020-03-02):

UPS-lite 1.2 UART

umbynos, 2020-03-02:
Hello, is it possible to access UART functionality on UPS-lite version 1.2? I'm asking because the dip switches are not present..

linshuqin329, 2020-03-06:
hi ，the UPS-lite version 1.2 has remove the  UART chip CP2104，so it didn't have the UART functionality。

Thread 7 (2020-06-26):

It just works

edwardxml, 2020-06-26:
Hi,

This isn't really an 'Issue', but a comment.

I was expecting all sorts of trouble with this device - especially when Google couldn't find me any documentation on the web. It is good that this Github is listed on the box. Biggest problem I had was realising the big switch at the end of the board had to be set to 'On'.

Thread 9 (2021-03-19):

Power Adapter Unplug always

rknobbe, 2021-03-19:
Using UPS-Lite V1.2 on a Raspberry Pi Zero WH, GPIO input 4 is always low regardless of whether power is applied or not.

ThatOneRoadie, 2021-03-25:
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
Pad 1 is open and will not show adapter plugged in until soldered together.

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

rknobbe, 2021-04-06:
Thanks!

Closed 2021-04-06.

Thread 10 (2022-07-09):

New order on aliexpr and had to modify the script

ser, 2022-07-09:
Hi, I've just bought UPSlite v1.2 on aliexpress and I have a small issue:
```
# i2cdetect -y 1
     0  1  2  3  4  5  6  7  8  9  a  b  c  d  e  f
00:                         -- -- -- -- -- -- -- --
10: -- -- -- -- -- -- -- -- -- -- -- -- -- -- -- --
20: -- -- -- -- -- -- -- -- -- -- -- -- -- -- -- --
30: -- -- 32 -- -- -- -- -- -- -- -- -- -- -- -- --
40: -- -- -- -- -- -- -- -- -- -- -- -- -- -- -- --
50: -- -- -- -- -- -- -- -- -- -- -- -- -- -- -- --
60: -- -- -- -- -- -- -- -- -- -- -- -- -- -- -- --
70: -- -- -- -- -- -- -- --           
```
It's on 0x32 not on 0x36 anymore.

I also had to modify the script to read capacity:

```
def readCapacity(bus):
        "This function returns as a float the remaining capacity of the battery connected to the Raspi UPS Hat via the provided SMBus object"
        address = 0x32
        read = bus.read_word_data(address, 4)
        swapped = struct.unpack("<H", struct.pack(">H", read))[0]
        capacity = swapped/256-100
        return capacity
```

linshuqin329, 2022-10-09:
Hello, I can post your UPS-Lite photos for me. I want to confirm whether you bought the fake UPS-Lite. Someone copied my product, and then sold on aliexpress

maxromanovsky, 2022-10-09:
@linshuqin329  I had the same issue with the second UPS-Lite I bought. I bought it on Shopee, and it was definitely fake. Wires from the battery were thin, it had spelling mistakes. On/off switch was different... I sent it back and waiting for refund. And it had the same different I2C address.

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

linshuqin329, 2022-10-10:
@maxromanovsky  yes, this UPS-Lite is fake, it is not my product

maxromanovsky, 2022-10-10:
@linshuqin329 where can I buy your original product?

linshuqin329, 2022-10-10:
@maxromanovsky  here. https://www.tindie.com/products/rachel/ups-lite-for-raspberry-pi-zero/

wjhrdy, 2022-10-10:
I fell for the same product [here](https://www.amazon.com/dp/B09YTTFRF6). My GPIO 4 is never reading HIGH and I cant decode the 32 bytes on the i2c block from address `0x76`.

```
from smbus2 import SMBus
with SMBus(1) as bus:
    print(bus.read_i2c_block_data(0x76, 0, 32))

> [255, 255, 120, 160, 0, 0, 0, 0, 0, 2, 255, 255, 151, 0, 255, 255, 255, 255, 255, 255, 0, 105, 255, 255, 255, 255, 255, 255, 255, 255, 255, 255]
```

linshuqin329, 2022-10-11:
@wjhrdy I need to see the UPS-Lite physical photo on your hand. From the pictures of Amazon, I cannot judge whether your UPS-Lite is my product

wjhrdy, 2022-10-11:
![Uploading PXL_20221011_032929792.jpg…]()

wjhrdy, 2022-10-11:
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

linshuqin329, 2022-10-11:
@wjhrdy I confirmed that this is a fake UPS-Lite

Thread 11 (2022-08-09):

Power Raspberry PI through it's own power port when UPS Lite is powered on

maxromanovsky, 2022-08-09:
Hi!
I haven't found it in manual, and want to clarify.
Is it okay if:
- UPS Lite is connected to Raspberry
- UPS Lite is turned on
- Charger is connected Raspberry PI own USB power port

Will I damage RPI or UPS Lite?

linshuqin329, 2022-10-09:
I don't recommend this, this may damage the UPS-Lite，It is recommended that the Raspberry Pi is power supply only by UPS-Lite

maxromanovsky, 2022-10-09:
Awesome, thanks!

Closed 2022-10-09.

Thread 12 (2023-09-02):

ups lite 1.3 don't recognize charging

Havivw, 2023-09-02:
GPIO 4 always returns low
Does someone know how to recognize if charging?

Dimon-GDA, 2023-12-16:
Check this issue https://github.com/linshuqin329/UPS-Lite/issues/5

Havivw, 2023-12-21:
Thank you

Closed 2023-12-21.

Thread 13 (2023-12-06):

Is there an official shop on Taobao 淘寶, AliExpress, or Amazon?

fumin, 2023-12-06:
I want to buy this great UPS-Lite, only from you the true creator, but I only use Taobao 淘寶, AliExpress, or Amazon.
What is your official shop on Taobao 淘寶, AliExpress, or Amazon?
Can you put it in the README?

我想從你的官方商店買 UPS-Lite，請問你在 淘寶, AliExpress, 或 Amazon的官方商店是甚麼?
可以把你的官方商店的連結 URL寫在 README裡面嗎?

linshuqin329, 2023-12-13:
@fumin  this is my tindie store    https://www.tindie.com/products/rachel/ups-lite-for-raspberry-pi-zero/

fumin, 2023-12-13:
Got it, will be using this store, thanks.

Closed 2023-12-13.

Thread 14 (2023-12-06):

Does UPS-Lite support the second generation Pi Zero 2 W

fumin, 2023-12-06:
As title, specifically does UPS-Lite support this:

https://www.raspberrypi.com/products/raspberry-pi-zero-2-w/

I think the answer is yes, since:

* the form factor of the Pi Zero 2 is the same as the first version
* the Pi Zero 2 draws less than 500mA, while the UPS-Lite can provide 1.3A.

Nonetheless, it would be great if this support can be explicitly spelled out in the docs, such as in the README or [V1.2.pdf](https://github.com/linshuqin329/UPS-Lite/blob/master/UPS-Lite_V1.2_MAX17040G/Instructions%20for%20UPS-Lite%20V1.2.pdf).

linshuqin329, 2023-12-13:
@fumin  yes ，it is support  ZERO 2W

fumin, 2023-12-13:
Got you, thanks. Would be great as an advertisement if this could be spelled out in the README. : )

Closed 2023-12-13.

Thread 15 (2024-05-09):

UPS-Lite V1.2 - Replacing the original battery with an 18650 battery

xt2six, 2024-05-09:
Good morning,

I have a problem with the original battery of assembly 1.2. Before starting the repair, I would like to have your opinion if I should keep the circuit soldered to the original battery (HLN 1832-6 - chips KIA SEMICONDUCTORS - 8205a) to place it on a 1 x 18650 battery holder?

What amp capacity do you recommend for 18650 batteries? (1,200?)

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

xt2six, 2024-06-03:
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

Good evening linshuqin329, thank you for these details.

I finally opted to use a terminal block but it is not practical to manage an 18650 battery holder which is larger than the raspberry pi zero. So I gave up and bought another card which doesn't really meet my needs but it provides an 18650 battery slot (GEEKWORM X306 - UPS ; but why a hub USB ... and no RJ45..., no RTC...)

Thanks for support !

xt2six, 2024-06-04:
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

Good evening linshuqin329, thank you for these details.

I finally opted to use a terminal block but it is not practical to manage an 18650 battery holder which is larger than the raspberry pi zero. So I gave up and bought another card which doesn't really meet my needs but it provides an 18650 battery slot (GEEKWORM X306 - UPS ; but why a hub USB ... and no RJ45..., no RTC...)

Thanks for support !

Closed 2024-06-04.

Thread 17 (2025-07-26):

Feature reuqest: compatibility with Rock Zero

giovi321, 2025-07-26:
I did some research and basically yes, you can physically mount UPS‑Lite V1.3 on a ROCK ZERO 3W and even electrically power it that way.
On a good node:
- Power lines line up, and the ZERO 3W will run off the 5 V header pins
However:
- I²C on pins 3/5 is on bus 3, so I should tweak any UPS‑Lite scripts to open /dev/i2c-3 instead of bus 1
- GPIO detection code (BCM 4) must be rewritten using a Rockchip‑compatible GPIO library or direct sysfs/device‑tree handling.
It would be nice to have this possibility, unfortunately I am not capable of doing something like this.

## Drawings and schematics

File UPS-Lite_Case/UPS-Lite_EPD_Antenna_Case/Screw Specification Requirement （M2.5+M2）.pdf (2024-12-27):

## UPS-Lite Case Matching Screw Specification Requirement

### UPS-Lite 外壳配套螺丝规格要求

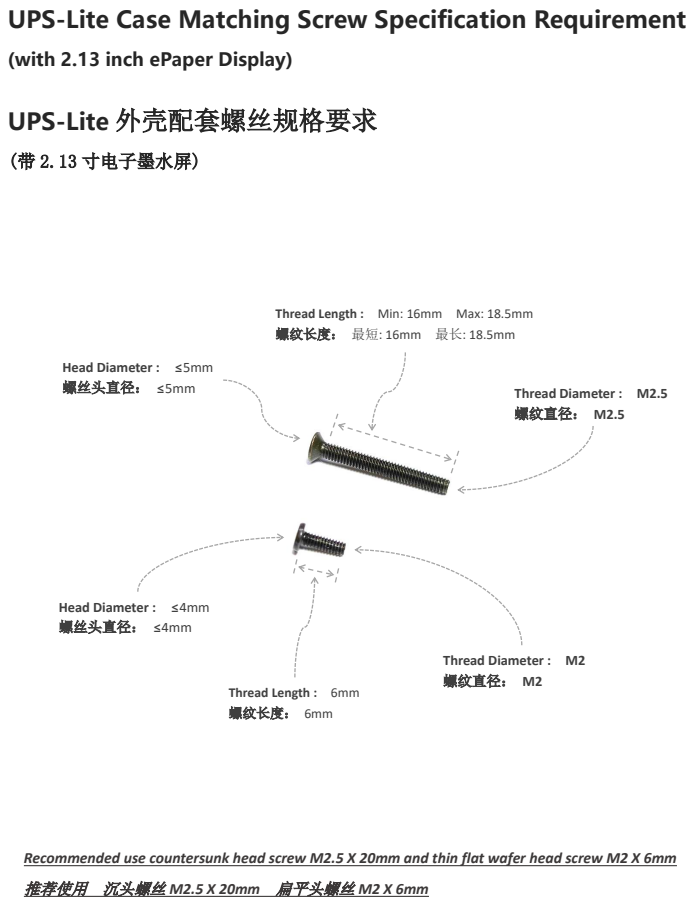
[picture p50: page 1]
(带 2.13 寸电子墨水屏); Head Diameter : ≤5mm; 螺丝头直径： ≤5mm; Thread Diameter : M2.5; 螺纹直径： M2.5; Head Diameter : ≤4mm 螺丝头直径： ≤4mm; Thread Length : 6mm; 螺纹长度： 6mm; Thread Diameter : M2 螺纹直径： M2

(with 2.13 inch ePaper Display)

Thread Length : Min: 16mm Max: 18.5mm
螺纹长度： 最短: 16mm 最长: 18.5mm

Recommended use countersunk head screw M2.5 X 20mm and thin flat wafer head screw M2 X 6mm
推荐使用 沉头螺丝 M2.5 X 20mm 扁平头螺丝 M2 X 6mm

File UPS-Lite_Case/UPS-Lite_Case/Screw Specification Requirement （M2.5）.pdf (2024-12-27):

# UPS-Lite Case Matching Screw Specification Requirement

## UPS-Lite 外壳配套螺丝规格要求

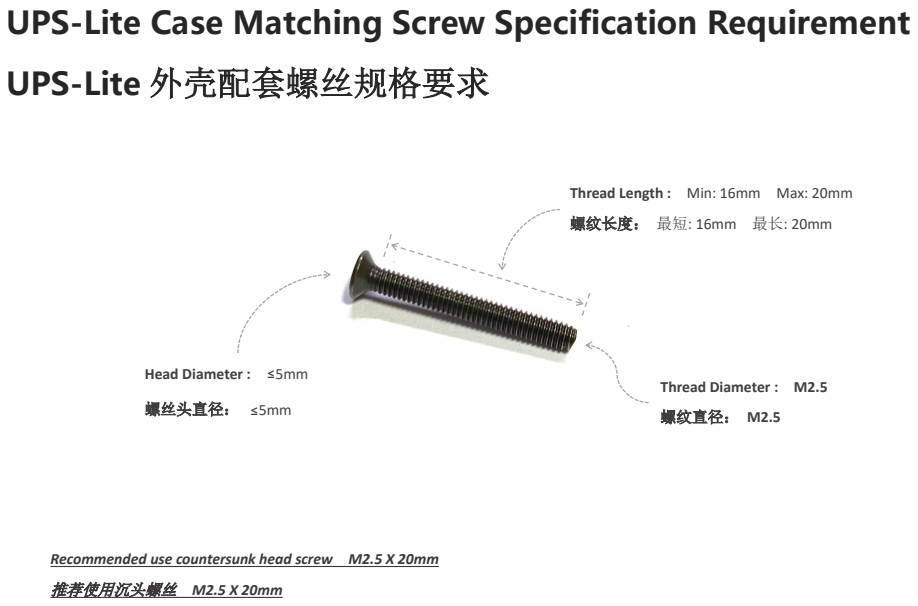
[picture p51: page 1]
Head Diameter : ≤5mm; 螺丝头直径： ≤5mm; Thread Diameter : M2.5; 螺纹直径： M2.5

Thread Length : Min: 16mm Max: 20mm
螺纹长度： 最短: 16mm 最长: 20mm

Recommended use countersunk head screw M2.5 X 20mm
推荐使用沉头螺丝 M2.5 X 20mm

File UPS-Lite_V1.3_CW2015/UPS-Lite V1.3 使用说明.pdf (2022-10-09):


## 1. 简介

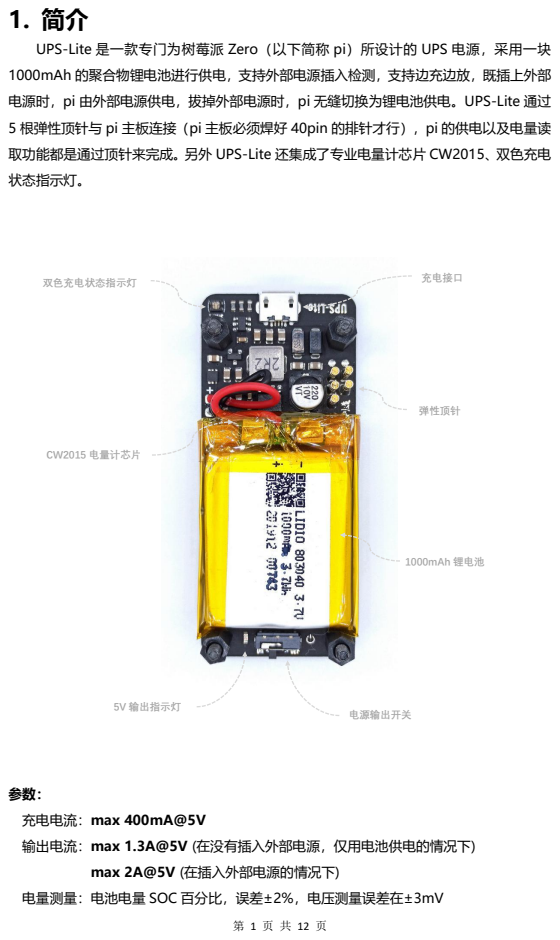
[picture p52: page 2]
max 2A@5V (在插入外部电源的情况下); 电源输出开关; 1000mAh 锂电池; 弹性顶针; 充电接口; 5V 输出指示灯; 双色充电状态指示灯; CW2015 电量计芯片

UPS-Lite 是一款专门为树莓派 Zero（以下简称 pi）所设计的 UPS 电源，采用一块
1000mAh 的聚合物锂电池进行供电，支持外部电源插入检测，支持边充边放，既插上外部
电源时，pi 由外部电源供电，拔掉外部电源时，pi 无缝切换为锂电池供电。UPS-Lite 通过
5 根弹性顶针与 pi 主板连接（pi 主板必须焊好 40pin 的排针才行），pi 的供电以及电量读
取功能都是通过顶针来完成。另外 UPS-Lite 还集成了专业电量计芯片 CW2015、双色充电
状态指示灯。

充电电流：max 400mA@5V
输出电流：max 1.3A@5V (在没有插入外部电源，仅用电池供电的情况下)

电量测量：电池电量 SOC 百分比，误差±2%，电压测量误差在±3mV

2.安装

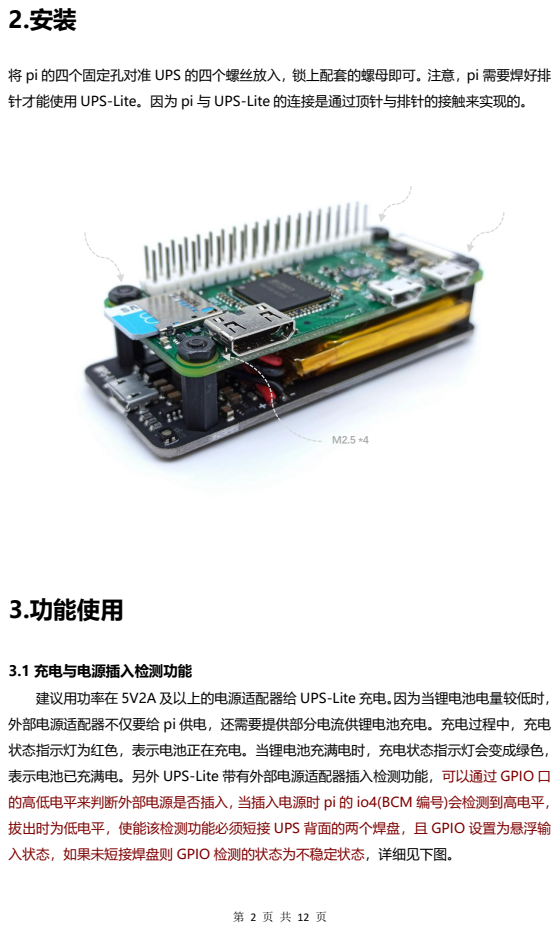
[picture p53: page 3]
3.功能使用

将 pi 的四个固定孔对准 UPS 的四个螺丝放入，锁上配套的螺母即可。注意，pi 需要焊好排
针才能使用 UPS-Lite。因为 pi 与 UPS-Lite 的连接是通过顶针与排针的接触来实现的。

3.1 充电与电源插入检测功能
建议用功率在 5V2A 及以上的电源适配器给 UPS-Lite 充电。因为当锂电池电量较低时，
外部电源适配器不仅要给 pi 供电，还需要提供部分电流供锂电池充电。充电过程中，充电
状态指示灯为红色，表示电池正在充电。当锂电池充满电时，充电状态指示灯会变成绿色，
表示电池已充满电。另外 UPS-Lite 带有外部电源适配器插入检测功能，可以通过 GPIO 口
的高低电平来判断外部电源是否插入，当插入电源时 pi 的 io4(BCM 编号)会检测到高电平，
拔出时为低电平，使能该检测功能必须短接 UPS 背面的两个焊盘，且 GPIO 设置为悬浮输
入状态，如果未短接焊盘则 GPIO 检测的状态为不稳定状态，详细见下图。

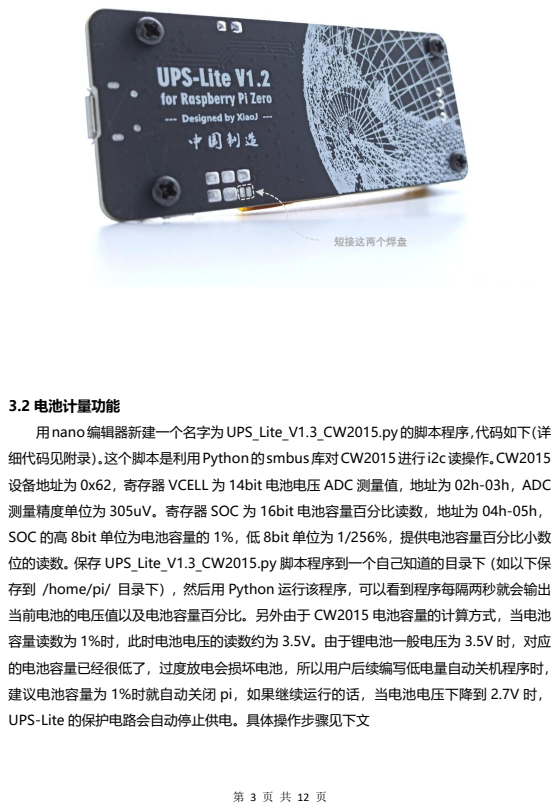
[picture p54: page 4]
短接这两个焊盘

3.2 电池计量功能
用nano编辑器新建一个名字为UPS_Lite_V1.3_CW2015.py的脚本程序，代码如下（详
细代码见附录）。这个脚本是利用Python的smbus库对CW2015进行i2c读操作。CW2015
设备地址为 0x62，寄存器 VCELL 为 14bit 电池电压 ADC 测量值，地址为 02h-03h，ADC
测量精度单位为 305uV。寄存器 SOC 为 16bit 电池容量百分比读数，地址为 04h-05h，
SOC 的高 8bit 单位为电池容量的 1%，低 8bit 单位为 1/256%，提供电池容量百分比小数
位的读数。保存 UPS_Lite_V1.3_CW2015.py 脚本程序到一个自己知道的目录下（如以下保
存到 /home/pi/ 目录下），然后用 Python 运行该程序，可以看到程序每隔两秒就会输出
当前电池的电压值以及电池容量百分比。另外由于 CW2015 电池容量的计算方式，当电池
容量读数为 1%时，此时电池电压的读数约为 3.5V。由于锂电池一般电压为 3.5V 时，对应
的电池容量已经很低了，过度放电会损坏电池，所以用户后续编写低电量自动关机程序时，
建议电池容量为 1%时就自动关闭 pi，如果继续运行的话，当电池电压下降到 2.7V 时，
UPS-Lite 的保护电路会自动停止供电。具体操作步骤见下文

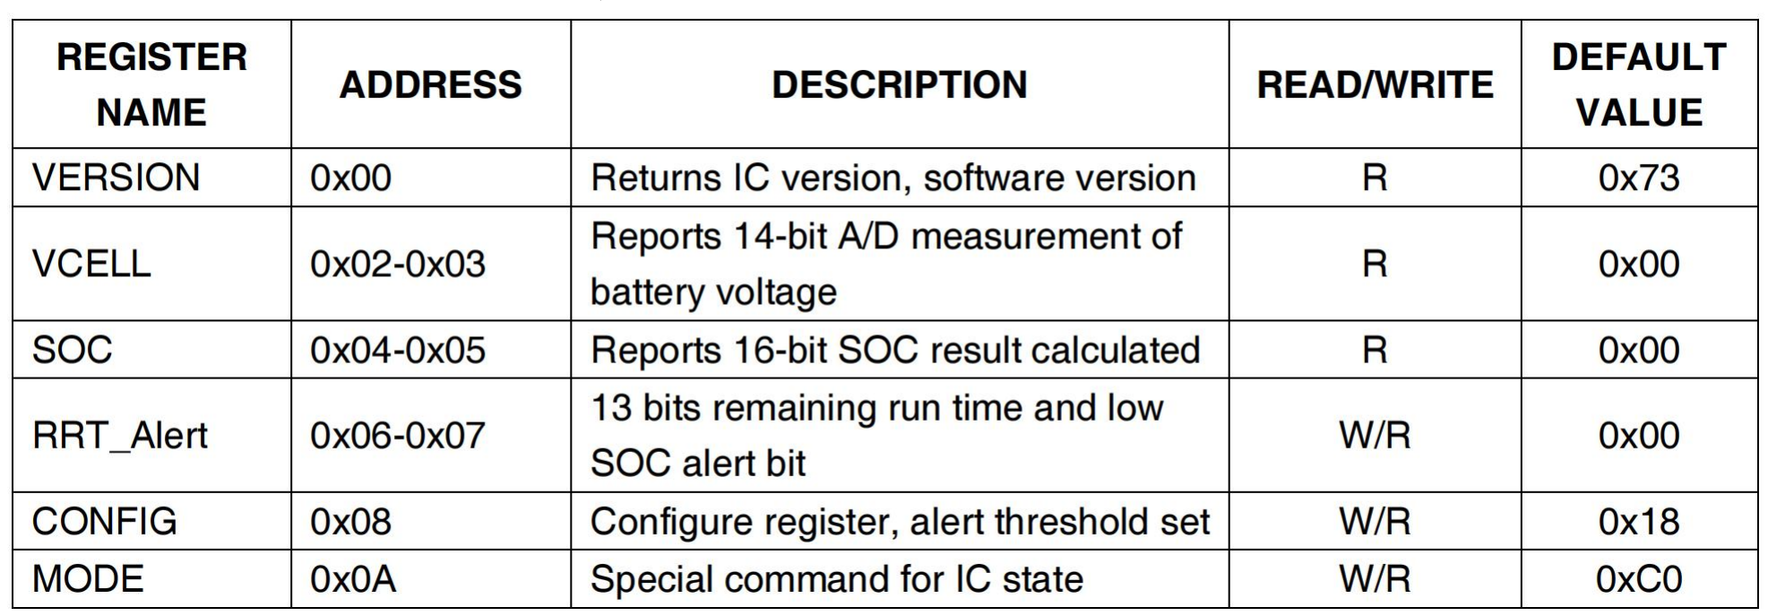
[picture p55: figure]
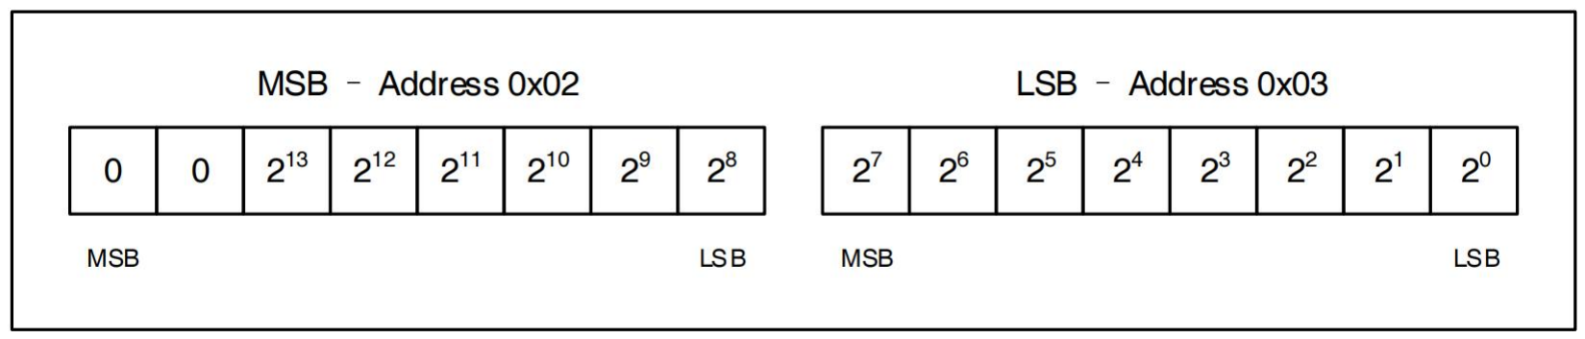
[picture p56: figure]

第 4 页 共 12 页

CW2015 寄存器地址以及功能介绍

VCELL 寄存器

SOC 寄存器

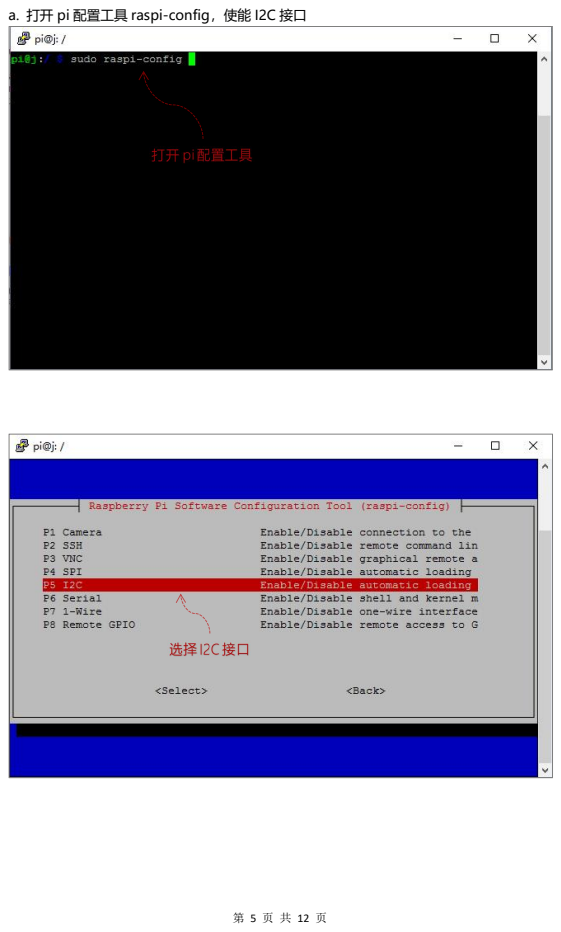
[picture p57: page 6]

a. 打开 pi 配置工具 raspi-config，使能 I2C 接口

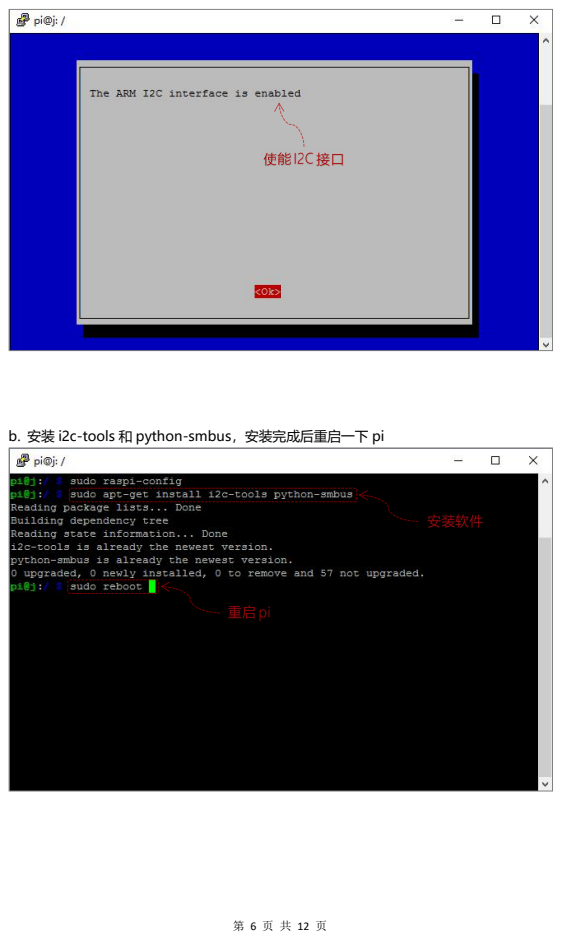
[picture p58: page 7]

b. 安装 i2c-tools 和 python-smbus，安装完成后重启一下 pi

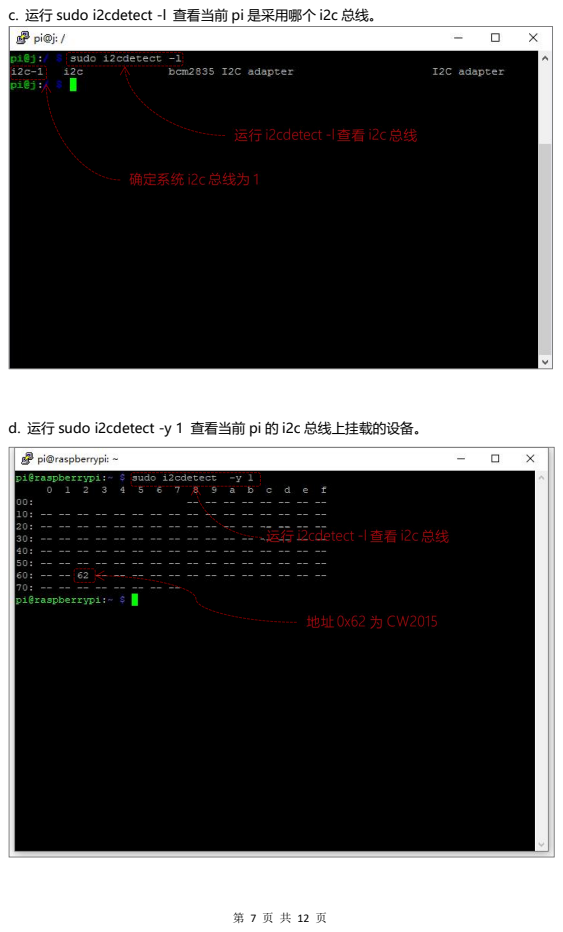
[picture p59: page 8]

c. 运行 sudo i2cdetect -l 查看当前 pi 是采用哪个 i2c 总线。

d. 运行 sudo i2cdetect -y 1 查看当前 pi 的 i2c 总线上挂载的设备。

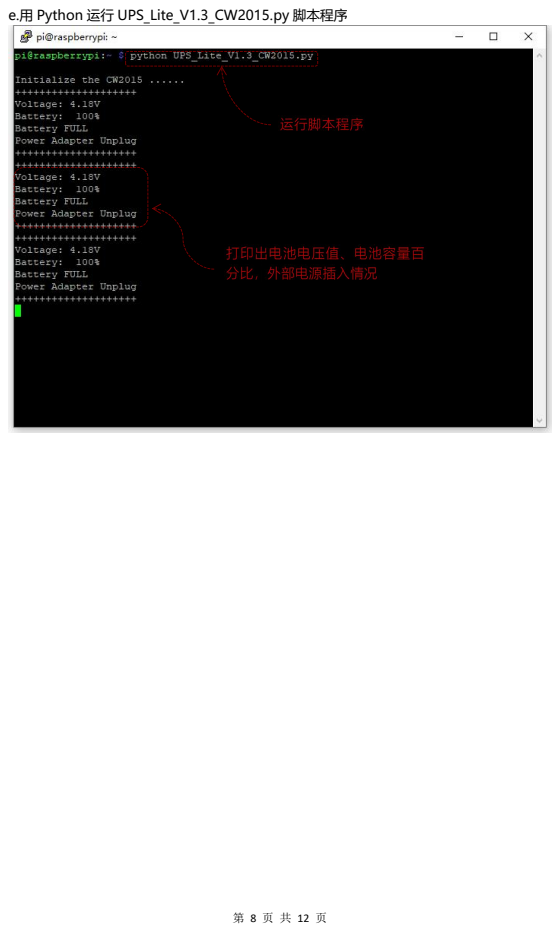
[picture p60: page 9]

e.用 Python 运行 UPS_Lite_V1.3_CW2015.py 脚本程序

第 9 页 共 12 页

附录：

UPS_Lite_V1.3_CW2015.py 的脚本程序代码：

#!/usr/bin/env | python

import | struct
import | smbus
import | sys
import | time
import | RPi.GPIO | as | GPIO
CW2015_ADDRESS | | = | 0X62
CW2015_REG_VCELL | = | 0X02
CW2015_REG_SOC | | = | 0X04
CW2015_REG_MODE | | = | 0X0A
def | readVoltage(bus):
| | | | "This function returns as float the voltage from the Raspi UPS Hat
via | the | provided | SMBus | object"
| | | | read | = | bus.read_word_data(CW2015_ADDRESS, | | | | CW2015_REG_VCELL)
| | | | swapped | = | struct.unpack("<H", | | | | struct.pack(">H", | read))[0]
| | | | voltage | = | swapped | * | 0.305 | /1000
| | | | return | voltage
def | readCapacity(bus):
| | | | "This | function | returns | as | a | float | | the | remaining | capacity | of | the
battery | connected | to | the | Raspi | UPS | Hat | via | the | provided | | SMBus | object"
| | | | read | = | bus.read_word_data(CW2015_ADDRESS, | | | | CW2015_REG_SOC)
| | | | swapped | = | struct.unpack("<H", | | | | struct.pack(">H", | | | | read))[0]
| | | | capacity | = | swapped/256
| | | | return | capacity
def | QuickStart(bus): "This function wake up the CW2015 and make a quick-start fuel-gauge
calculations | "
| | bus.write_word_data(CW2015_ADDRESS, | CW2015_REG_MODE, | 0x30)

第 10 页 共 12 页

#--------------------------------------------------------------------GPIO.setmode(GPIO.BCM)

GPIO.setwarnings(False)
GPIO.setup(4,GPIO.IN) | | | # GPIO4 is used to detect whether an external power
supply | is | inserted
bus = smbus.SMBus(1) | # 0 = /dev/i2c-0 (port I2C0), 1 = /dev/i2c-1 (port
I2C1)
QuickStart(bus)
print | (" | | ")
print | ("Initialize | the | | CW2015 | ......")
while | True:
print | ("++++++++++++++++++++")
print | ("Voltage:%5.2fV" | % | readVoltage(bus))
print | ("Battery:%5i%%" | % | readCapacity(bus))
if | readCapacity(bus) | == | 100:
| | print | ("Battery | FULL")
if | readCapacity(bus) | < | 5:
| | print | ("Battery | LOW")
#GPIO | | is | | high | when | power | is | | plugged | | in

| if | | (GPIO.input(4) | | | | | == | | GPIO.HIGH):
| | | | | | print | ("Power | | | Adapter | | Plug | In | ")
| if | | (GPIO.input(4) | | | | | == | | GPIO.LOW):
| | | | | | print | ("Power | | | Adapter | | Unplug")
print | ("++++++++++++++++++++")
time.sleep(2)


第 11 页 共 12 页

部分参考原理图：


如果使用上有其他问题的话可以联系我：416386001@qq.com

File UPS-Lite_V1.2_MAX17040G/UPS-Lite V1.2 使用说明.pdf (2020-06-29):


# 1. 简介

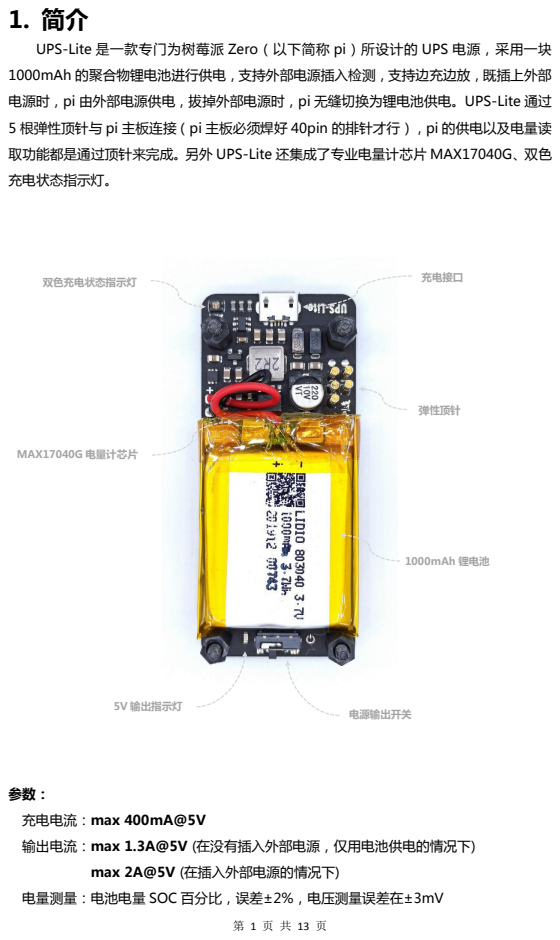
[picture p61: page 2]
max 2A@5V (在插入外部电源的情况下); 电源输出开关; 1000mAh 锂电池; 弹性顶针; 充电接口; 5V 输出指示灯; 双色充电状态指示灯; MAX17040G 电量计芯片

UPS-Lite 是一款专门为树莓派 Zero（以下简称 pi）所设计的 UPS 电源，采用一块
1000mAh 的聚合物锂电池进行供电，支持外部电源插入检测，支持边充边放，既插上外部
电源时，pi 由外部电源供电，拔掉外部电源时，pi 无缝切换为锂电池供电。UPS-Lite 通过
5 根弹性顶针与 pi 主板连接（pi 主板必须焊好 40pin 的排针才行），pi 的供电以及电量读
取功能都是通过顶针来完成。另外 UPS-Lite 还集成了专业电量计芯片 MAX17040G、双色
充电状态指示灯。

充电电流：max 400mA@5V
输出电流：max 1.3A@5V (在没有插入外部电源，仅用电池供电的情况下)

电量测量：电池电量 SOC 百分比，误差±2%，电压测量误差在±3mV

2.安装

3.功能使用

将 pi 的四个固定孔对准 UPS 的四个螺丝放入，锁上配套的螺母即可。注意，pi 需要焊好排
针才能使用 UPS-Lite。因为 pi 与 UPS-Lite 的连接是通过顶针与排针的接触来实现的。

3.1 充电与电源插入检测功能
建议用功率在 5V2A 及以上的电源适配器给 UPS-Lite 充电。因为当锂电池电量较低时，
外部电源适配器不仅要给 pi 供电，还需要提供部分电流供锂电池充电。充电过程中，充电
状态指示灯为红色，表示电池正在充电。当锂电池充满电时，充电状态指示灯会变成绿色，
表示电池已充满电。另外 UPS-Lite 带有外部电源适配器插入检测功能，可以通过 GPIO 口
的高低电平来判断外部电源是否插入，当插入电源时 pi 的 io4(BCM 编号)会检测到高电平，
拔出时为低电平，使能该检测功能必须短接 UPS 背面的两个焊盘，且 GPIO 设置为悬浮输
入状态，如果未短接焊盘则 GPIO 检测的状态为不稳定状态，详细见下图。

短接这两个焊盘

3.2 电池计量功能
用nano 编辑器新建一个名字为 UPS_Lite.py的脚本程序，代码如下（详细代码见附录）。
这个脚本是利用 Python 的 smbus 库对 MAX17040G 进行 i2c 读操作。MAX17040G 设
备地址为 0x36，寄存器 VCELL 为 12bit 电池电压 ADC 测量值，地址为 02h-03h，ADC
测量精度单位为 1.25mV。寄存器 SOC 为 16bit 电池容量百分比读数，地址为 04h-05h，
SOC 的高 8bit 单位为电池容量的 1%，低 8bit 单位为 1/256%，提供电池容量百分比小数
位的读数。保存 UPS_Lite.py 脚本程序到一个自己知道的目录下（如以下保存到 /home/pi/
目录下），然后用 Python 运行该程序，可以看到程序每隔两秒就会输出当前电池的电压值
以及电池容量百分比。另外由于 MAX17040G 电池容量的计算方式，当电池容量读数为 1%
时，此时电池电压的读数约为 3.5V。由于锂电池一般电压为 3.5V 时，对应的电池容量已经
很低了，过度放电会损坏电池，所以用户后续编写低电量自动关机程序时，建议电池容量为
1%时就自动关闭 pi，如果继续运行的话，当电池电压下降到 2.7V 时，UPS-Lite 的保护电
路会自动停止供电。具体操作步骤见下文


第 4 页 共 13 页

MAX17040G 寄存器地址以及功能介绍

VCELL 寄存器

SOC 寄存器


a. 打开 pi 配置工具 raspi-config，使能 I2C 接口


b. 安装 i2c-tools 和 python-smbus，安装完成后重启一下 pi


c. 运行 sudo i2cdetect -l 查看当前 pi 是采用哪个 i2c 总线。

d. 运行 sudo i2cdetect -y 1 查看当前 pi 的 i2c 总线上挂载的设备。


第 8 页 共 13 页

e. 用 nano 编辑器新建以下 UPS_Lite.py 脚本程序（详细代码见附录）

f.用 Python 运行该脚本程序

第 10 页 共 13 页

附录：

UPS_Lite.py 的脚本程序代码：

#!/usr/bin/env python

import struct
import smbus
import sys
import time
import RPi.GPIO as GPIO

def readVoltage(bus):

"This function returns as float the voltage from the Raspi UPS Hat via the provided SMBus object"
address = 0x36
read = bus.read_word_data(address, 0X02)
swapped = struct.unpack("<H", struct.pack(">H", read))[0] voltage = swapped * 1.25 /1000/16
return voltage

def readCapacity(bus):
"This function returns as a float the remaining capacity of the battery connected to the Raspi UPS Hat via the provided SMBus object"
address = 0x36
read = bus.read_word_data(address, 0X04)
swapped = struct.unpack("<H", struct.pack(">H", read))[0] capacity = swapped/256
return capacity

def QuickStart(bus):
address = 0x36
bus.write_word_data(address, 0x06,0x4000)

def PowerOnReset(bus):
address = 0x36
bus.write_word_data(address, 0xfe,0x0054)

GPIO.setmode(GPIO.BCM)
GPIO.setwarnings(False)
GPIO.setup(4,GPIO.IN)

第 11 页 共 13 页

bus = smbus.SMBus(1) # 0 = /dev/i2c-0 (port I2C0), 1 = /dev/i2c-1 (port I2C1)

PowerOnReset(bus)
QuickStart(bus)

print " "
print "Initialize the MAX17040 ......"

while True:

print "++++++++++++++++++++"
print "Voltage:%5.2fV" % readVoltage(bus) print "Battery:%5i%%" % readCapacity(bus)

if readCapacity(bus) == 100:
print "Battery FULL"

if readCapacity(bus) < 5:
print "Battery LOW"

if (GPIO.input(4) == GPIO.HIGH): print "Power Adapter Plug In "

if (GPIO.input(4) == GPIO.LOW): print "Power Adapter Unplug"

print "++++++++++++++++++++" time.sleep(2)


第 12 页 共 13 页

部分参考原理图：


参考资料：

树莓派学习笔记——I2C Tools 学习笔记 - CSDN 博客
http://blog.csdn.net/xukai871105/article/details/15029843

MAX17040 结构紧凑的低成本 1S/2S 电量计 - Maxim 美信 https://www.maximintegrated.com/cn/products/power/battery-management/MAX17040.html

如果使用上有其他问题的话可以联系我：416386001@qq.com

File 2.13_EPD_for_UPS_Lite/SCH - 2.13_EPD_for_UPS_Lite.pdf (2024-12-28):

# PI 40 GPIO

# 2.13" E-paper Display for UPS-Lite - - by XiaoJ
